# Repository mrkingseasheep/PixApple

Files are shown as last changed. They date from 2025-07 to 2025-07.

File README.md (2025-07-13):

# PixApple

PixApple is designed as a RP2040 breakout board. It features 8 general use GPIOs, 1 SPI interface, 1 I2C interface, 4 ADC channels, 4 PWM channels and a CAN bus.
I designed it because I wanted a board that I could use for general purpose robotics projects. Being from FRC, a CAN bus was a must so I added the CAN bus onto the RP2040 with split terminations.
The Roborio is like 2000CAD so it's so far out of reach its funny. Of course, I don't need the real time OS or the robust nature of the thing, I just want to drive a lil car or something. So I created this!
Building this project really gave me a greater understanding of what went on undernearth the Roborio (I never did open it) and everything actually kinda makes sense now.
I chose the RP2040 because it is cheap, decently powerful for the basic robotics I plan on doing with it and is also what I'm used to.
Additionally, I chose the 0603 SMT format because I wanted to be able to fix any problems I have later on with this board.
This being V1.0, many of the values are not tested and I wanted the ability to fix them if anything happened.
Finally, there are test points scattered around the board for easy debugging.

## What I've gained

Total time spent: 51 hours (I'm still so slow at KiCAD) (the redo didn't help)

This is my first semi-intermediate project and I wanted to learn more about ICs in general. I've incorporated: wide power traces, equal length wires and a ground pour on top and bottom in this project.

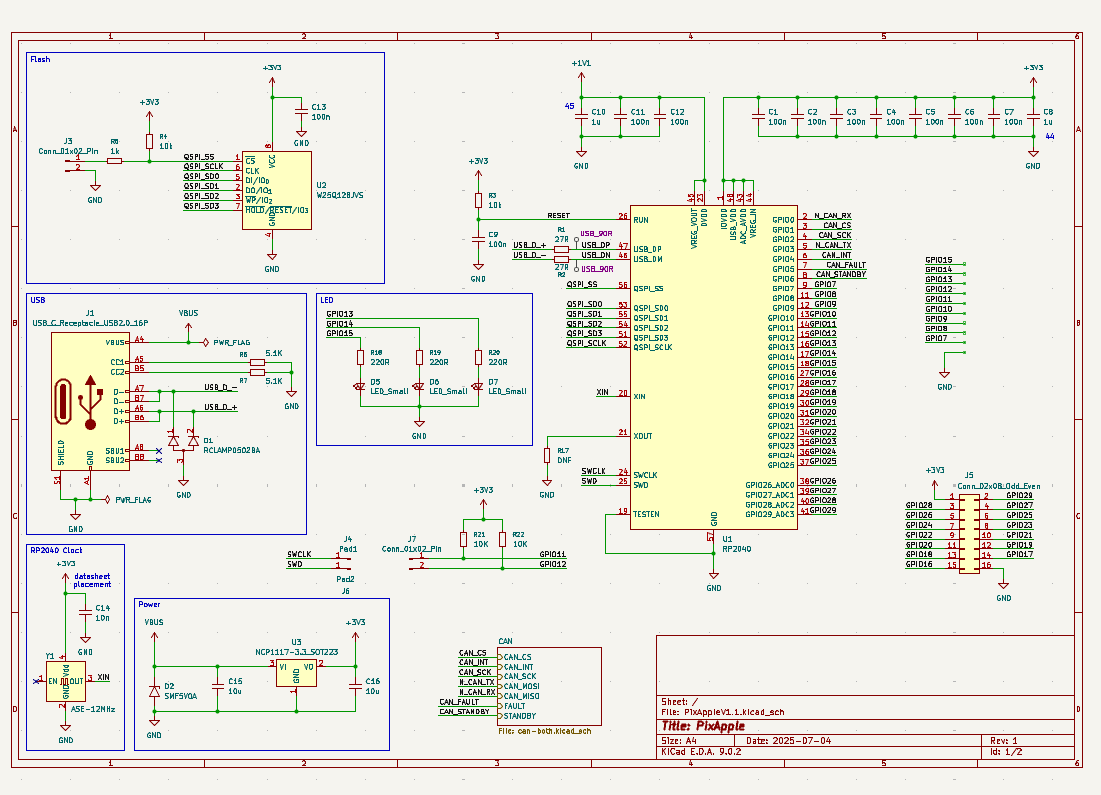
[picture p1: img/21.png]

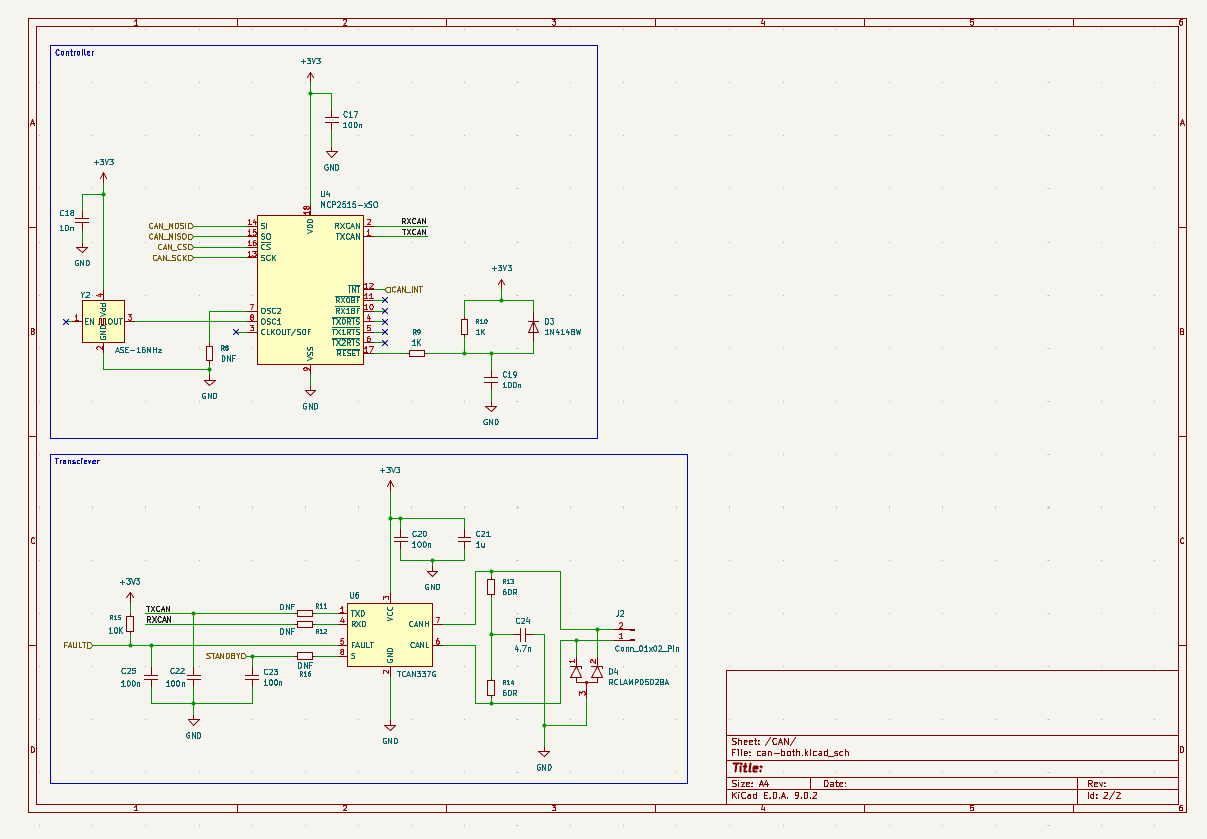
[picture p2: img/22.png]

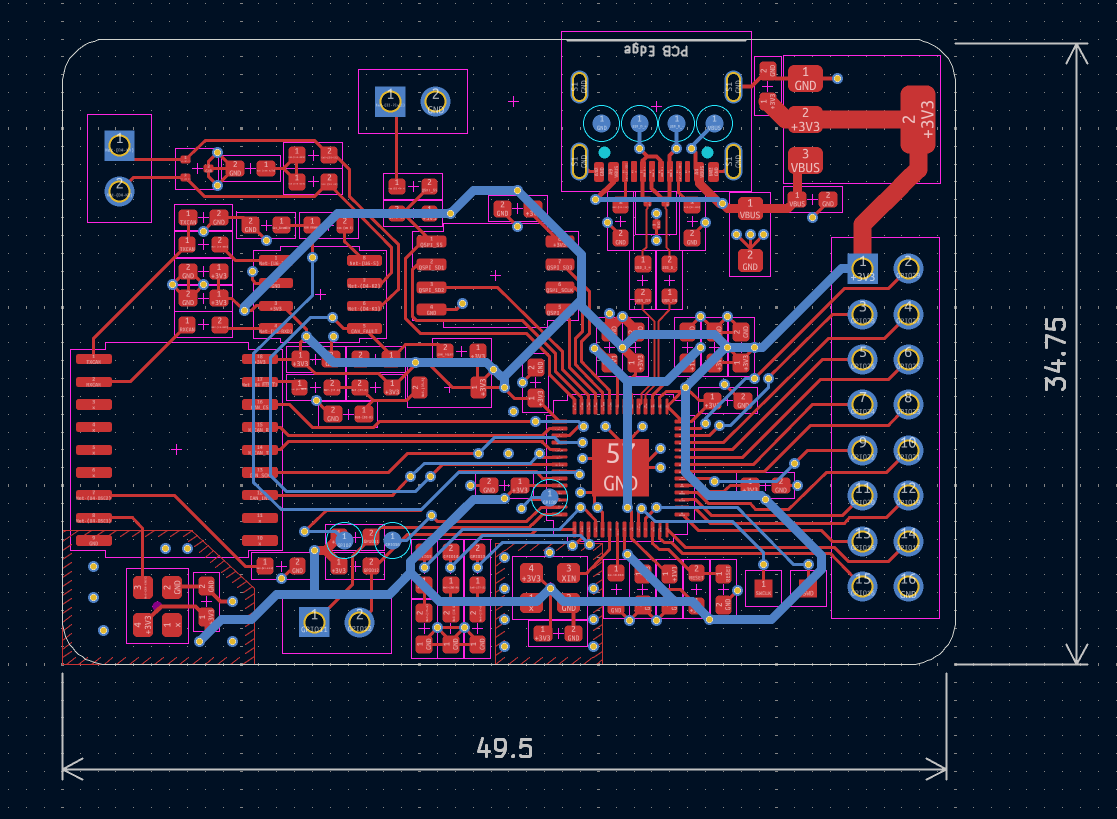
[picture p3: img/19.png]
PCB

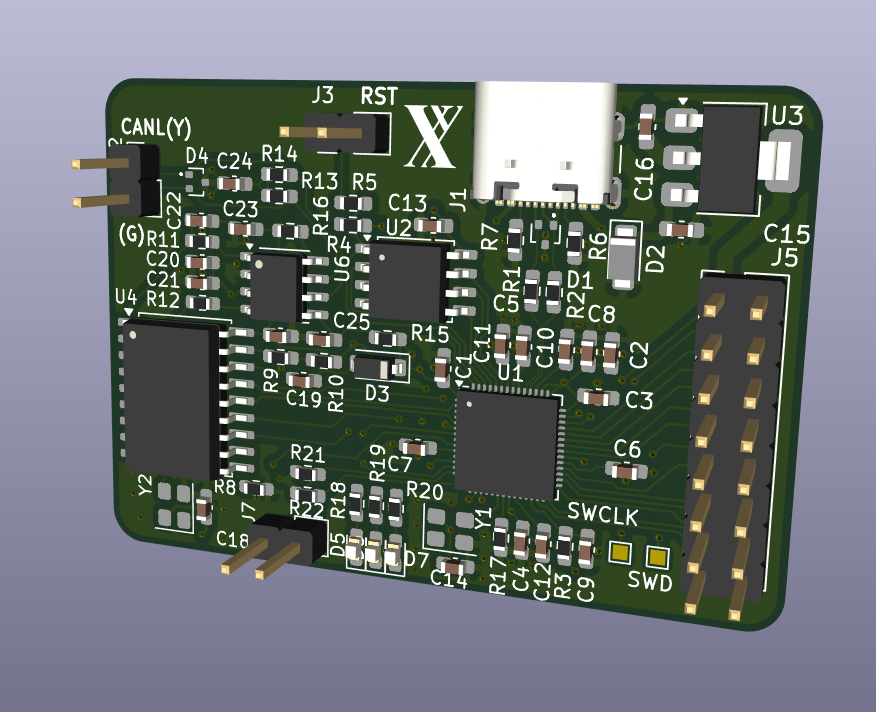
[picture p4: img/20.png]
3D

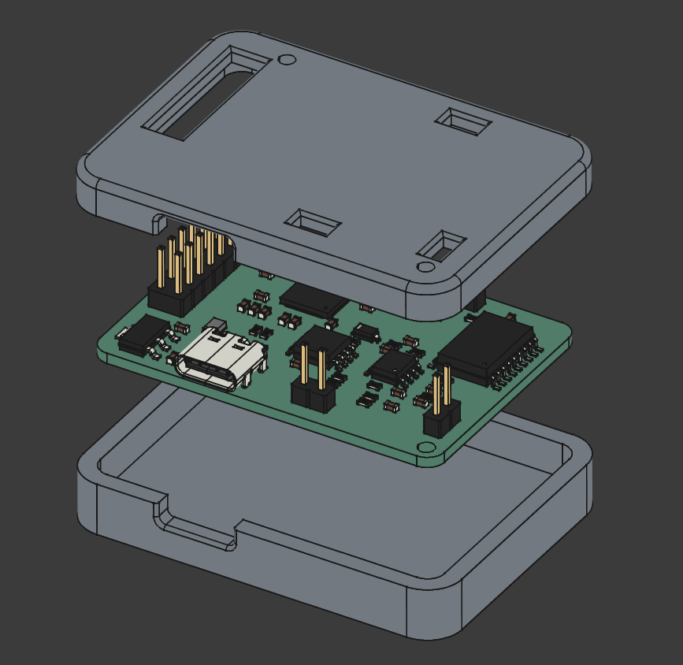
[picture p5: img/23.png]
Case

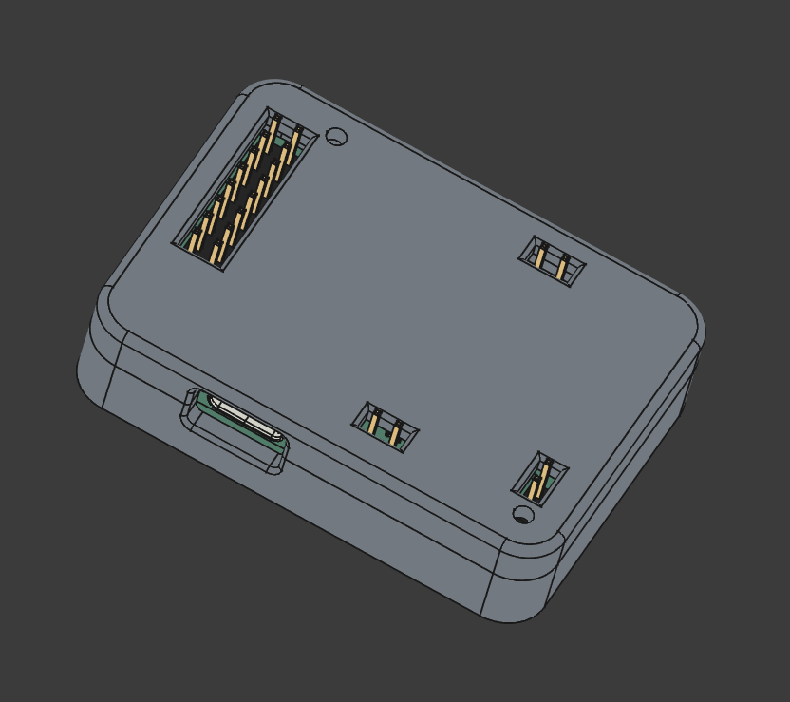
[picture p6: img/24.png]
Exploded


## BOM

| Quantity | Value | Cost | URL |
| --- | --- | --- | --- |
| 17 | Capacitor 100n | 0.068 | https://www.aliexpress.com/item/1005002782324319.html |
| 3 | Capacitor 1u | 0.012 | https://www.aliexpress.com/item/1005002782324319.html |
| 2 | Capacitor 10n | 0.008 | https://www.aliexpress.com/item/1005002782324319.html |
| 2 | Capacitor 10u | 0.008 | https://www.aliexpress.com/item/1005002782324319.html |
| 1 | Capacitor 4.7n | 0.004 | https://www.aliexpress.com/item/1005002782324319.html |
| 2 | TVS Diode RCLAMP0502BA | 2.50 | https://www.digikey.ca/en/products/detail/semtech-corporation/RCLAMP0502BATCT/2603604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 |
| 1 | SMF5V0A | 0.25 | https://www.digikey.ca/en/products/detail/vishay-general-semiconductor-diodes-division/SMF5V0A-E3-08/1680585 |
| 1 | 1N4148W | 0.014 | https://www.aliexpress.com/item/4000685043735.html |
| 3 | LED | 0.0525  | https://www.aliexpress.com/item/1005006211269173.html |
| 1 | USB_C_Receptacle_USB2.0_16P | 0.1875  | https://www.aliexpress.com/item/1005008515699009.html |
| 22 | 2.54mm Pins Male | 0.20295 | https://www.aliexpress.com/item/4001198421663.html |
| 2 | Resistor 27R | 0.01 | https://www.aliexpress.com/item/1005007902452631.html |
| 3 | Resistor 1K | 0.015 | https://www.aliexpress.com/item/1005007902452631.html |
| 5 | Resistor DNF | 0.025 | https://www.aliexpress.com/item/1005007902452631.html |
| 2 | Resistor 60R | 0.01 | https://www.aliexpress.com/item/1005007902452631.html |
| 5 | Resistor 10K | 0.025 | https://www.aliexpress.com/item/1005007902452631.html |
| 3 | Resistor 220R | 0.015 | https://www.aliexpress.com/item/1005007902452631.html |
| 2 | Resistor 5.1K | 0.01 | https://www.aliexpress.com/item/1005007902452631.html |
| 1 | RP2040 | 1.29 | https://www.canakit.com/raspberry-pi-rp2040.html?cid=cad&src=raspberrypi |
| 1 | W25Q128JVS | | JLCPCB Assembly |
| 1 | NCP1117-3.3_SOT223 | | JLCPCB Assembly |
| 1 | MCP2515-xSO | | JLCPCB Assembly |
| 1 | TCAN337G | | JLCPCB Assembly |
| 1 | ASE-12MHz | 1.56 | https://www.mouser.ca/ProductDetail/ABRACON/ASE-12.000MHZ-ET?qs=uDmhV2jwPRcj2BLg3gv24Q%3D%3D |
| 1 | ASE-16MHz | 1.53 | https://www.mouser.ca/ProductDetail/ABRACON/ASE-16.000MHZ-LC-T?qs=gt1LBUVyoHnfDWzQTg2whA%3D%3D |
| 1 | PCB | 75 | JLCPCB Assembly |
| 2 | Heat set insert | 0.10 | https://www.aliexpress.com/item/1005007653131713.html |
| 2 | M2 | 0.08 | https://www.aliexpress.com/item/32810872544.html |
| 1 | Case | 5 | Printing Legion |

Total: 80 CAD

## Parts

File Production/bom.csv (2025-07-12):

Designator | Footprint | Quantity | Value | LCSC Part #
C1, C11, C12, C13, C17, C19, C2, C20, C22, C23, C25, C3, C4, C5, C6, C7, C9 | 0603 | 17 | 100n
C10, C21, C8 | 0603 | 3 | 1u
C14, C18 | 0603 | 2 | 10n
C15, C16 | 0603 | 2 | 10u
C24 | 0603 | 1 | 4.7n
D1, D4 | SOT-416 | 2 | RCLAMP0502BA
D2 | D_SMF | 1 | SMF5V0A
D3 | D_SOD-123 | 1 | 1N4148W
D5, D6, D7 | 0603 | 3 | LED_Small
J1 | USB_C_Receptacle_GCT_USB4105-xx-A_16P_TopMnt_Horizontal | 1 | USB_C_Receptacle_USB2.0_16P
J2, J3, J7 | PinHeader_1x02_P2.54mm_Vertical | 3 | Conn_01x02_Pin
J5 | PinHeader_2x08_P2.54mm_Vertical | 1 | Conn_02x08_Odd_Even
R1, R2 | 0603 | 2 | 27R
R10, R5, R9 | 0603 | 3 | 1K
R11, R12, R16, R17, R8 | 0603 | 5 | DNF
R13, R14 | 0603 | 2 | 60R
R15, R21, R22, R3, R4 | 0603 | 5 | 10K
R18, R19, R20 | 0603 | 3 | 220R
R6, R7 | 0603 | 2 | 5.1K
SWCLK | TestPoint_Pad_1.0x1.0mm | 1 | Pad1
SWD | TestPoint_Pad_1.0x1.0mm | 1 | Pad2
U1 | QFN-56-1EP_7x7mm_P0.4mm_EP3.2x3.2mm | 1 | RP2040
U2 | SOIC-8_5.3x5.3mm_P1.27mm | 1 | W25Q128JVS
U3 | SOT-223-3_TabPin2 | 1 | NCP1117-3.3_SOT223
U4 | SOIC-18W_7.5x11.6mm_P1.27mm | 1 | MCP2515-xSO
U6 | SOIC-8_3.9x4.9mm_P1.27mm | 1 | TCAN337G
Y1 | Oscillator_SMD_Abracon_ASE-4Pin_3.2x2.5mm | 1 | ASE-12MHz
Y2 | Oscillator_SMD_Abracon_ASE-4Pin_3.2x2.5mm | 1 | ASE-16MHz

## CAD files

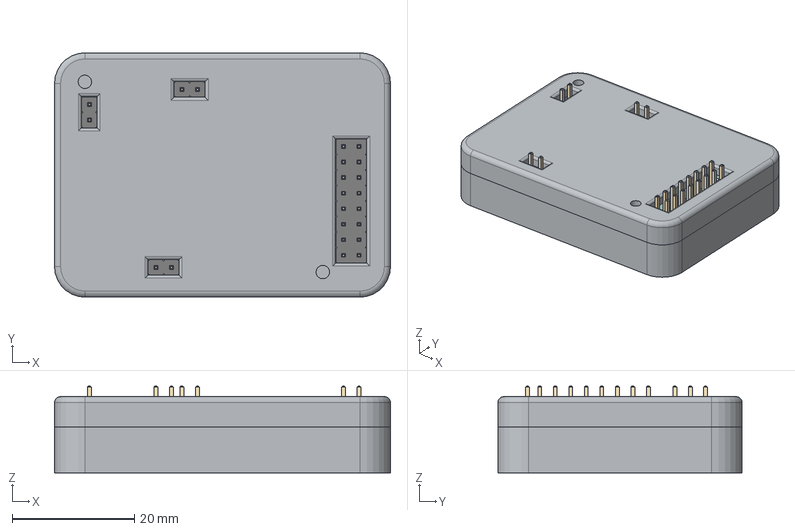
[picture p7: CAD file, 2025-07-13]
Case/case.step
55.0 x 40.0 x 14.2 mm
R_0603_1608Metric x 22
PinHeader_2x08_P2.54mm_Vertical
LED_0603_1608Metric x 3
C_0603_1608Metric x 25
SOIC-8_3.9x4.9mm_P1.27mm
SOIC-8_5.3x5.3mm_P1.27mm
D_SMF
SOT-223
D_SOD-123
QFN-56-1EP_7x7mm_P0.4mm_EP3.2x3.2mm
USB_C_Receptacle_GCT_USB4105-xx-A_16P_TopMnt_Horizontal
USB_C_Receptacle_GCT_USB4105-xx-A_16P_TopMnt_Horizontal001
USB_C_Receptacle_GCT_USB4105-xx-A_16P_TopMnt_Horizontal002
USB_C_Receptacle_GCT_USB4105-xx-A_16P_TopMnt_Horizontal003
USB_C_Receptacle_GCT_USB4105-xx-A_16P_TopMnt_Horizontal004
USB_C_Receptacle_GCT_USB4105-xx-A_16P_TopMnt_Horizontal005
USB_C_Receptacle_GCT_USB4105-xx-A_16P_TopMnt_Horizontal006
USB_C_Receptacle_GCT_USB4105-xx-A_16P_TopMnt_Horizontal007
USB_C_Receptacle_GCT_USB4105-xx-A_16P_TopMnt_Horizontal008
USB_C_Receptacle_GCT_USB4105-xx-A_16P_TopMnt_Horizontal009
USB_C_Receptacle_GCT_USB4105-xx-A_16P_TopMnt_Horizontal010
USB_C_Receptacle_GCT_USB4105-xx-A_16P_TopMnt_Horizontal011
USB_C_Receptacle_GCT_USB4105-xx-A_16P_TopMnt_Horizontal012
USB_C_Receptacle_GCT_USB4105-xx-A_16P_TopMnt_Horizontal013
USB_C_Receptacle_GCT_USB4105-xx-A_16P_TopMnt_Horizontal014
USB_C_Receptacle_GCT_USB4105-xx-A_16P_TopMnt_Horizontal015
USB_C_Receptacle_GCT_USB4105-xx-A_16P_TopMnt_Horizontal016
USB_C_Receptacle_GCT_USB4105-xx-A_16P_TopMnt_Horizontal017
USB_C_Receptacle_GCT_USB4105-xx-A_16P_TopMnt_Horizontal018
USB_C_Receptacle_GCT_USB4105-xx-A_16P_TopMnt_Horizontal019
USB_C_Receptacle_GCT_USB4105-xx-A_16P_TopMnt_Horizontal020
USB_C_Receptacle_GCT_USB4105-xx-A_16P_TopMnt_Horizontal021
USB_C_Receptacle_GCT_USB4105-xx-A_16P_TopMnt_Horizontal022
USB_C_Receptacle_GCT_USB4105-xx-A_16P_TopMnt_Horizontal023
USB_C_Receptacle_GCT_USB4105-xx-A_16P_TopMnt_Horizontal024
USB_C_Receptacle_GCT_USB4105-xx-A_16P_TopMnt_Horizontal025
USB_C_Receptacle_GCT_USB4105-xx-A_16P_TopMnt_Horizontal026
USB_C_Receptacle_GCT_USB4105-xx-A_16P_TopMnt_Horizontal027
USB_C_Receptacle_GCT_USB4105-xx-A_16P_TopMnt_Horizontal028
USB_C_Receptacle_GCT_USB4105-xx-A_16P_TopMnt_Horizontal029
USB_C_Receptacle_GCT_USB4105-xx-A_16P_TopMnt_Horizontal030
USB_C_Receptacle_GCT_USB4105-xx-A_16P_TopMnt_Horizontal031
USB_C_Receptacle_GCT_USB4105-xx-A_16P_TopMnt_Horizontal032
USB_C_Receptacle_GCT_USB4105-xx-A_16P_TopMnt_Horizontal033
USB_C_Receptacle_GCT_USB4105-xx-A_16P_TopMnt_Horizontal034
USB_C_Receptacle_GCT_USB4105-xx-A_16P_TopMnt_Horizontal035
PinHeader_1x02_P2.54mm_Vertical x 3
SOIC-18W_7.5x11.6mm_P1.27mm
PixAppleV1.1_PCB

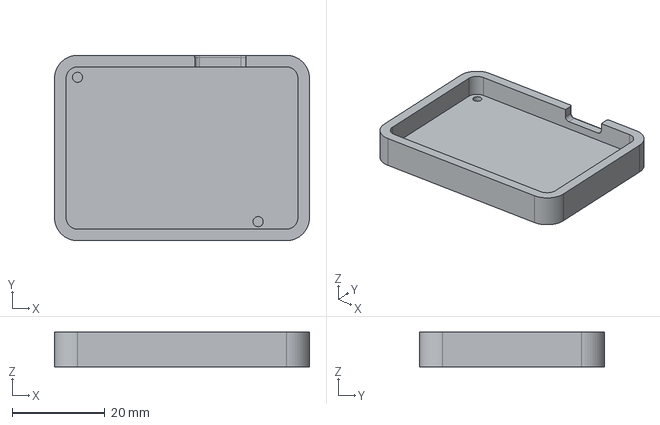
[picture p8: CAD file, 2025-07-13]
Production/case-bottom.step
55.0 x 40.0 x 7.50 mm

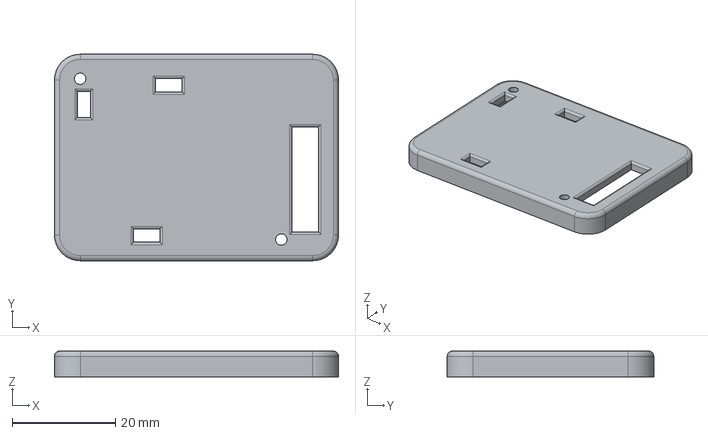
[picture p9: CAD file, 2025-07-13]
Production/case-top.step
55.0 x 40.0 x 5.00 mm

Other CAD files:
Case/case.FCStd

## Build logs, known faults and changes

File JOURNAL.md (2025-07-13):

---
title: "PixApple"
author: "Xinyang Wang"
description: "RP2040 Development Board"
created_at: "2025-07-04"
---

Total time spent: 38 hours (yes I'm slow)

# 2025-07-04 - Where to begin (5 hours)

This is a starter project so I can learn how to actually design a keyborad with the RP2040.
So far I've decided on Bluetooth support + battery charging.
I'm tempted to make it waterproof, whatever that means for a development board, so I can stick it in a submarine sometime in the future. Who knows. Maybe.
So far I've done the relatively basic task of setting it up with the power capacitors, pull up resistors and the likes. Only gripe I have right now is reading documentation is a chore.

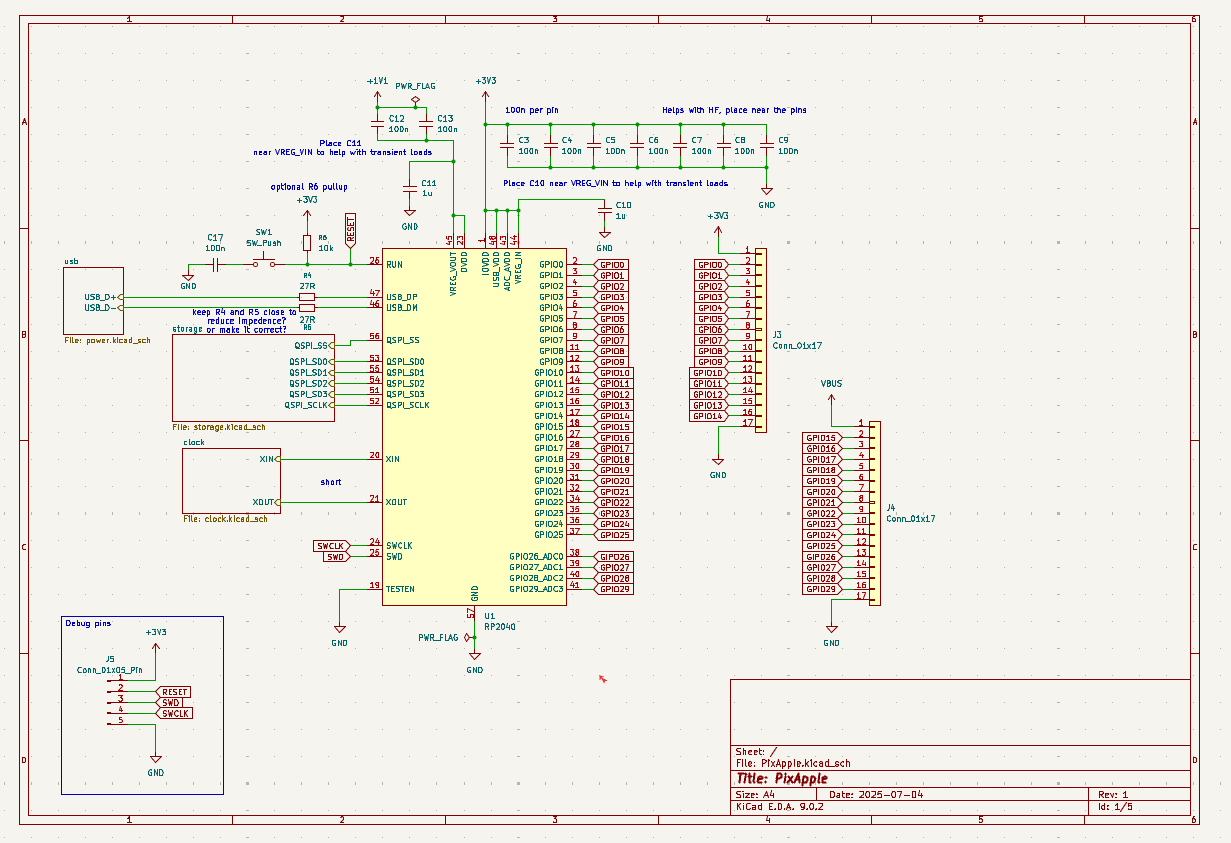
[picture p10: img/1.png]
Schematic start


# 2025-07-05 - CAN we do it? no (3 hours)

I want CAN. It'll make routing logic/commands/data to and from various parts a lot easier. Only problem is I have no idea what controllers to use. A preliminary search shows that the MCP2515 the CAN controller is a good fit but the transmitter the MCP2551 isn't. MCP2515 can handle +3V3 while MCP2551 needs +5V. So we're ditching MCP2551 for SN65HVD230. Whoever named these needs to be uhhh.... questioned.

Work is slow. So many pages of documentation on documentation. Mainly getting the crystal oscillator and reset pin of all things working. And guess what! My hirearchical sheet was drawn in the wrong grid size because I somehow clicked N by accident. That screws up all the tags and you can't connect to them. Now I have to redraw the sheet. I hate KiCAD sometimes. Why on earth would it let you change grid size if it'll break everything in the schematic??? I'm sleeping now.

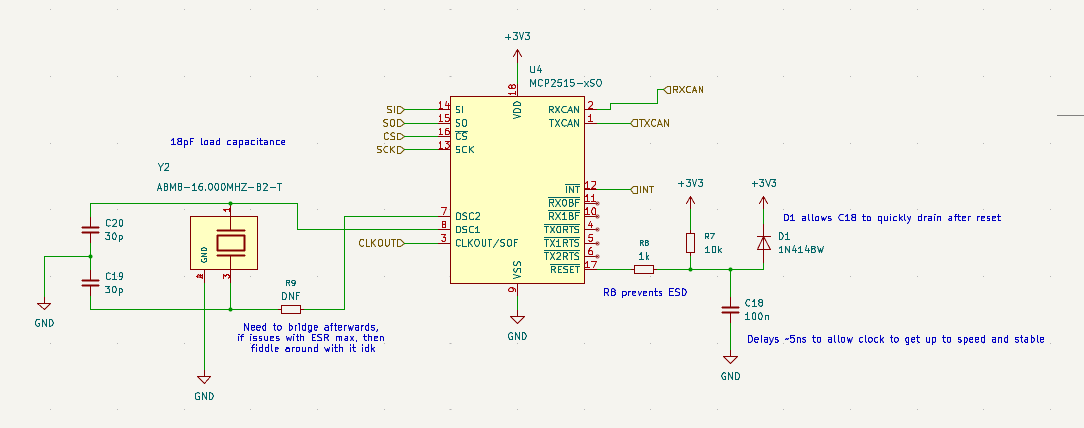
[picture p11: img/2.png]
MCP2515 design

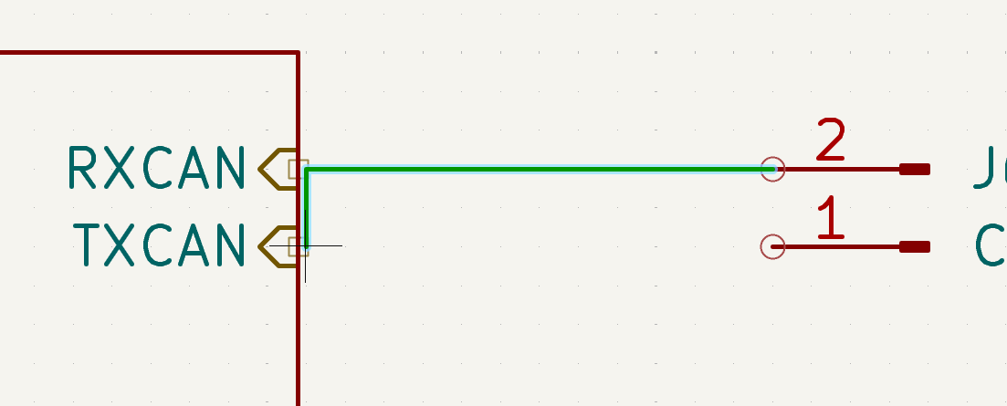
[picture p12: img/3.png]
GRRRRR


# 2025-07-06 - CAN re-schematic (5 hours)

Redo following (https://ww1.microchip.com/downloads/en/DeviceDoc/MCP2515-Stand-Alone-CAN-Controller-with-SPI-20001801J.pdf). Hopefully it went fine. The only thing that I'm slightly sketched out by is the series resistor R9 in the CAN clock. I'm not really sure how to calculate it and the ABM8-16MHz datasheet says nothing about it (https://abracon.com/Resonators/abm8.pdf). For now I'll just use the same resistor the RP2040 docs said to use with the ABM8-272 but hey at least I can desolder it if needed.

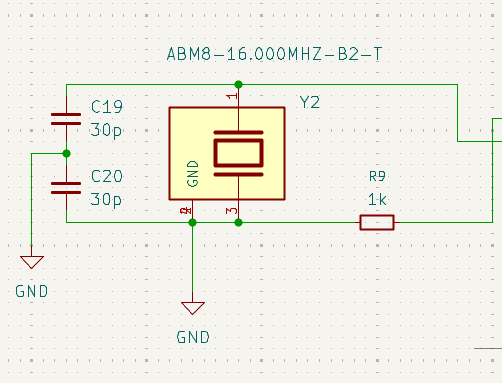
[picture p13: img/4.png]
Sketchyyy


Use this to figure out what pins the IC can actually connect to (https://datasheets.raspberrypi.com/rp2040/rp2040-datasheet.pdf).

DRC finally has no complaints! I hate rewiring though. Time to add the CAN transmitter (https://www.ti.com/lit/ds/symlink/sn65hvd230.pdf?ts=1751731839553). Yippee JLCPCB has it as a part (how much does assembly cost... I'm scared this'll be super super expensive). We're doing split termination on the CAN bus because we can. Also because I dunno if my signal will be clear at all so I'd much rather have a working CAN bus than a dysfunctional one. I finished schematic-ing up the CAN controller, the MCP2515 and the transmitter, the SN65HVD230DR.

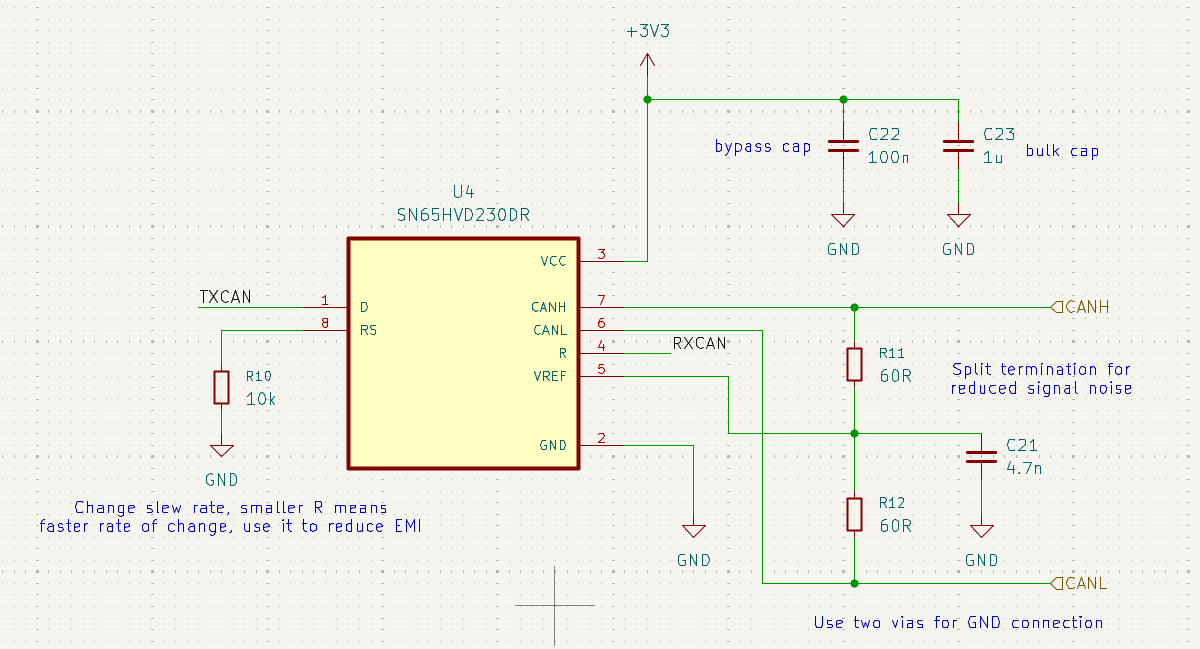
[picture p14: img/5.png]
CAN Done


# 2025-07-07 - Breakout (8 hours)

https://youtu.be/ySuUZEjARPY
Goated video.

Finished the schematic. Hopefully.

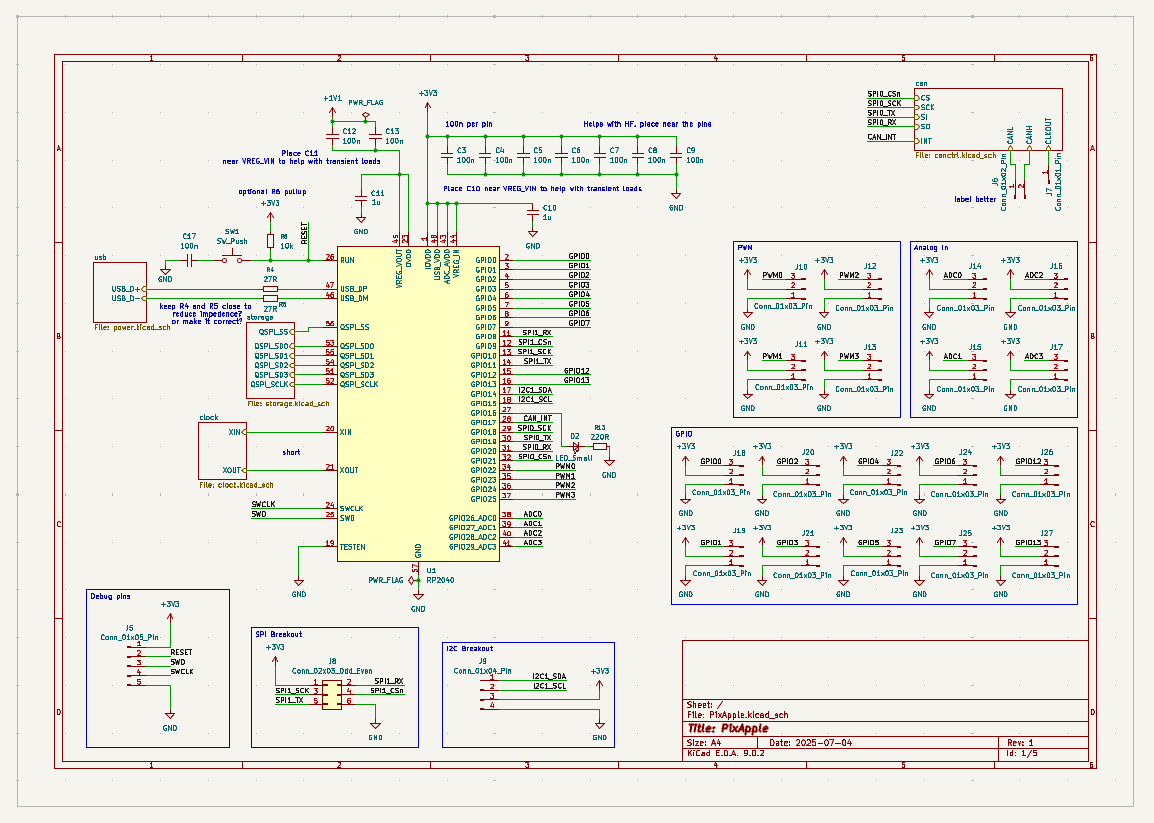
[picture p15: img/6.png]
Headers done


Added all footprints.

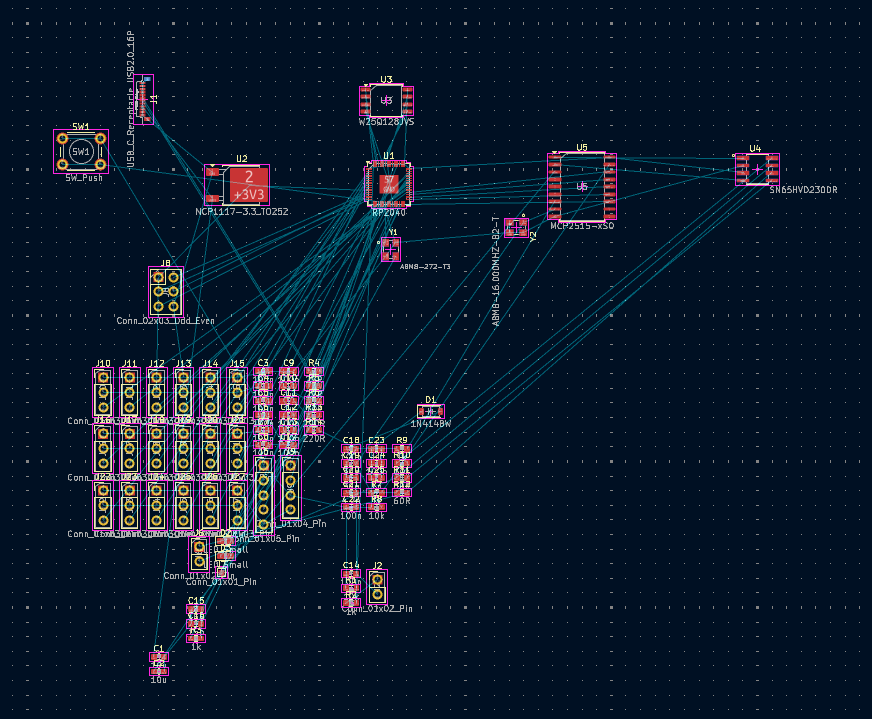
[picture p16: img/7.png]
One big rat


That was a total mess. I'll finish the rest of it tomorrow. Routing the CAN chip looks fun. The lines are all crossed and I'm scared that the vias will mess up the ground plane somehow.

# 2025-07-08 - Redo (6 hours)

Ok so uh I might be stupid and I might have placed all my components too close together. And uhhh... Well whoops they intersect physically so it's time for a complete redo. Yay. I'm having fun! (it is kinda fun though)

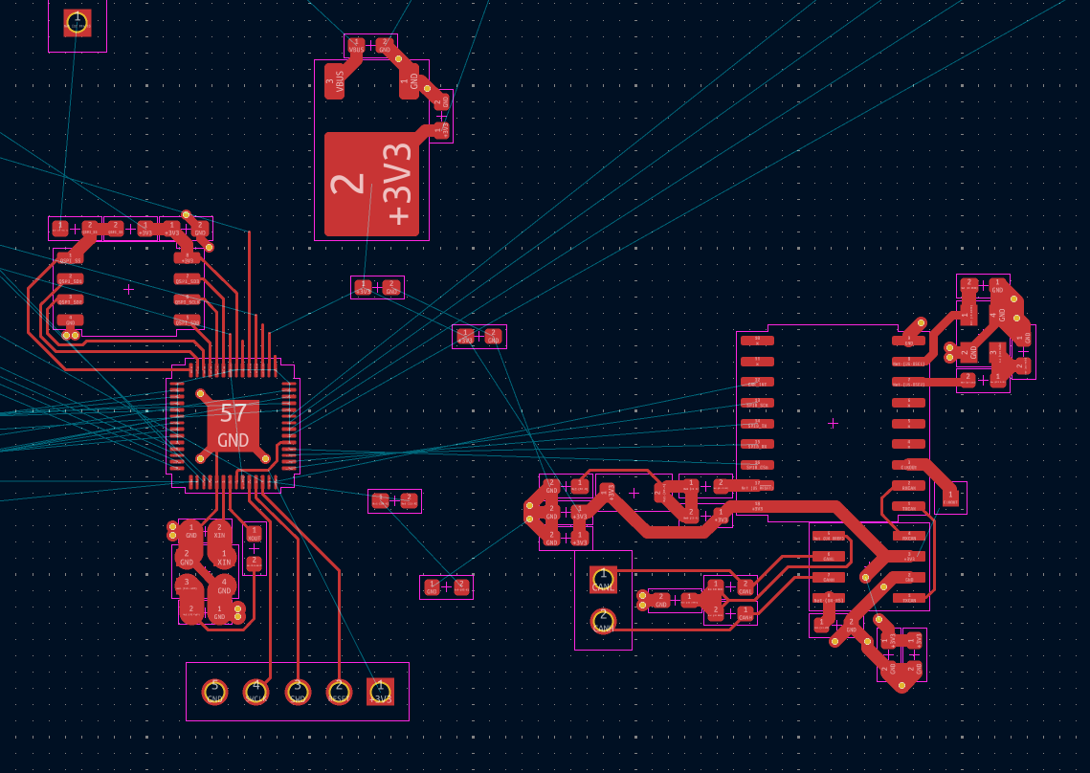
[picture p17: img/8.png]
Yet Another Redo

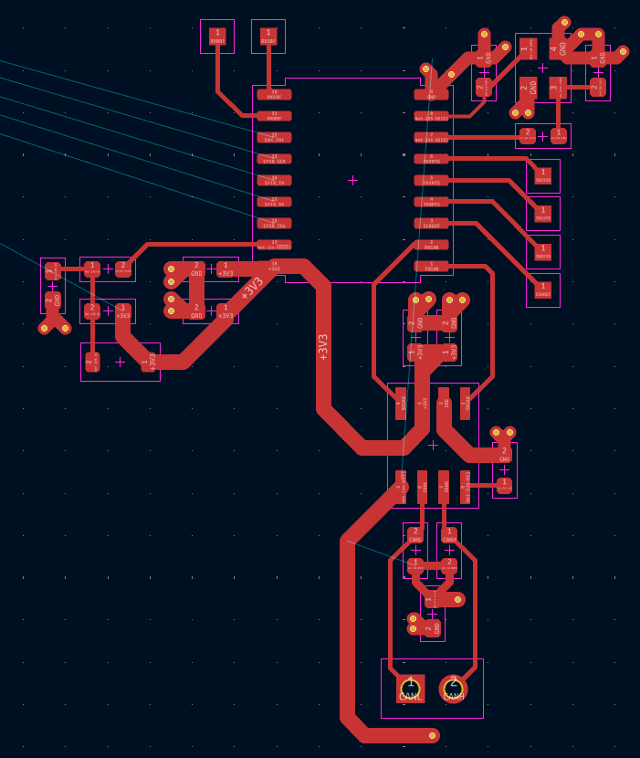
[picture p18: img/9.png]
Going well so far


Routing this is a pain. I'm using 0603 SMT parts because I want to practice soldering SMTs however that means that I can't fit my desired number of capacitors on the board. There's simply too many of them at the top of the RP2040 there. Alas.

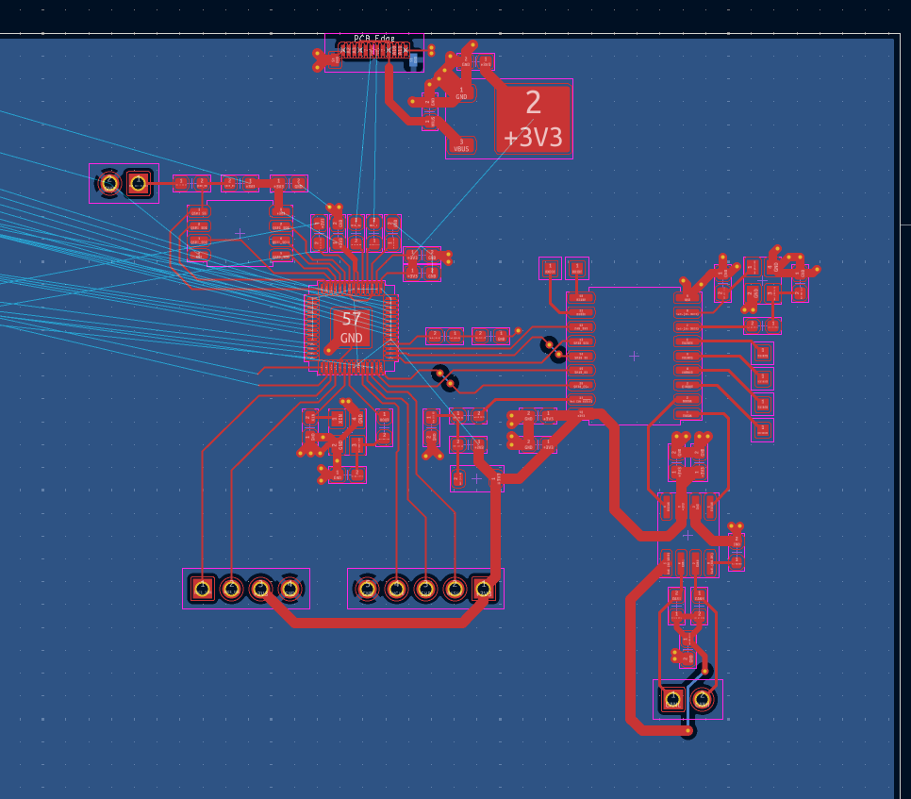
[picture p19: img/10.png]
PCB Design 101


# 2025-07-09 - FINALLY (8 hours)

It's done! Holy... It's been a journey. Routing the end was a pain and I'm 99% sure that the 0.9mm wide power traces will be fine. I didn't quite manage to use all the capacitors for the +3V3 but it should be fine. I think I might just finish by adding a connector for a battery or external +5V input. But then I'm done! Also the beveled edges are quite nice.

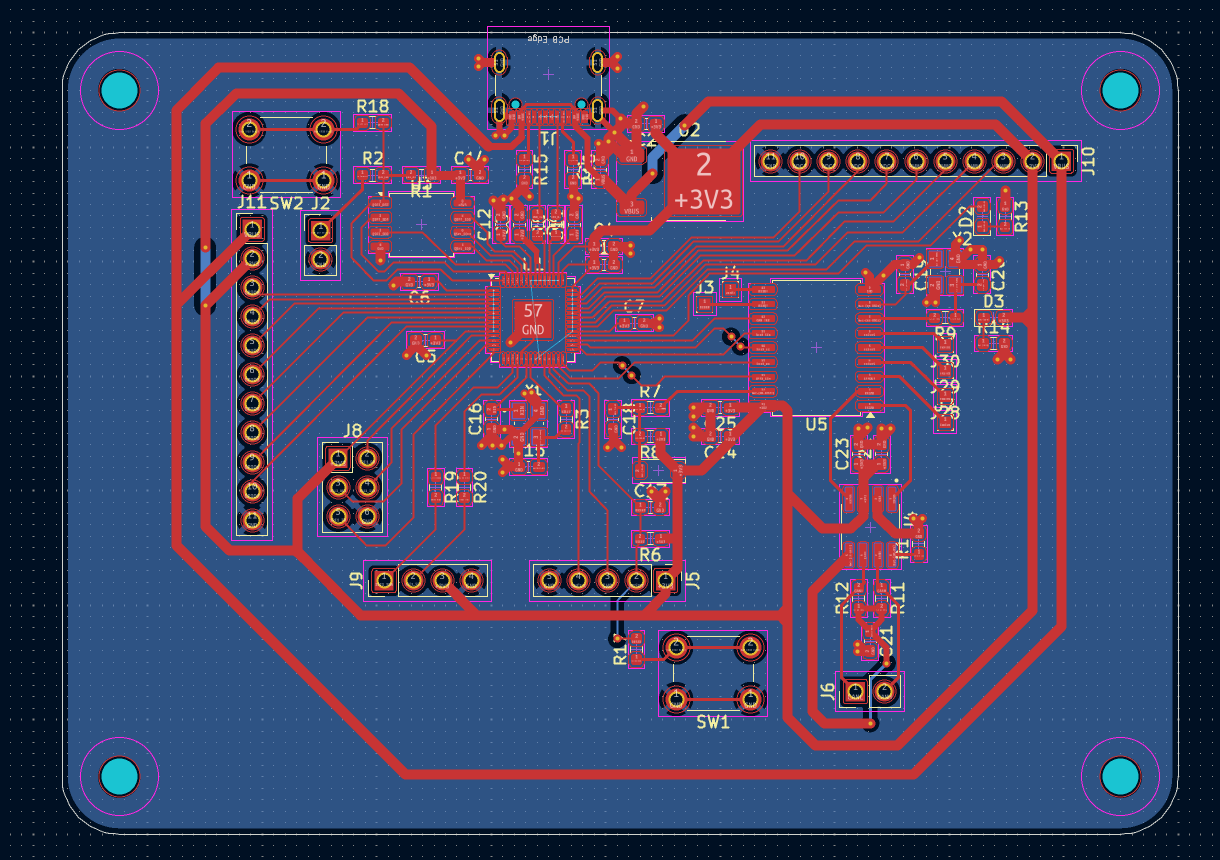
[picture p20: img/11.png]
99% Completion


Wait I just realized I need to fix the soldermask now oh dear. This'll be painful.
Update: It's done. I've added a power pin for battery power, diodes to prevent overflow, and a ground pour on the top layer.
All that's left is to add some decorative silkscreen and it'll be ready to ship.

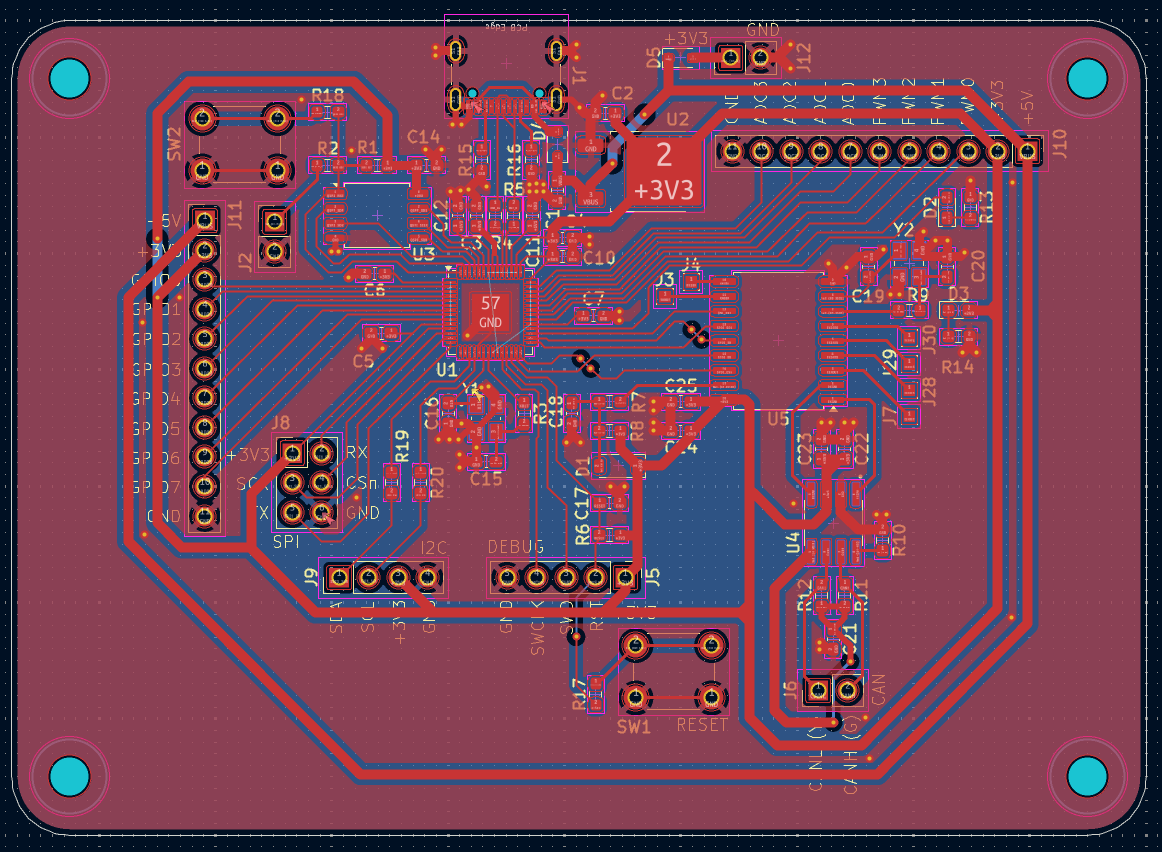
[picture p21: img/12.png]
We done

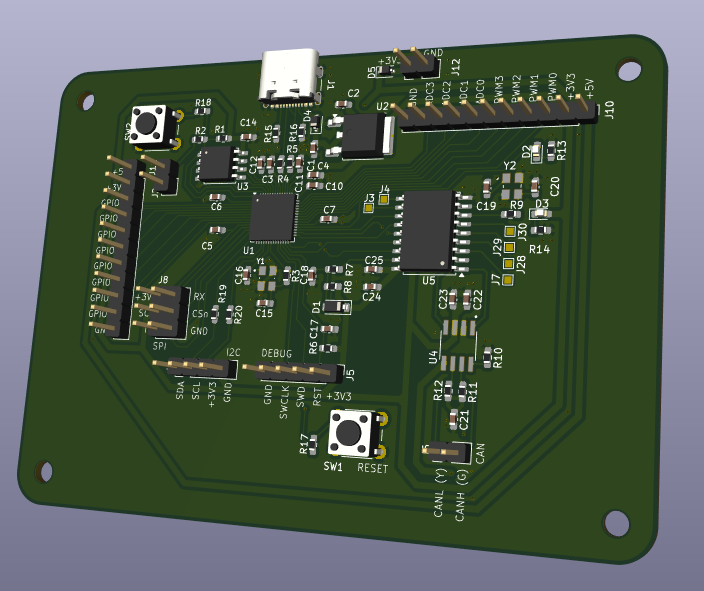
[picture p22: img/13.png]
Front


# 2025-07-10 - Final notes (3 hours)

Fixed the +3V3 and +1V1 rails, added ESD protection, better edge.cuts

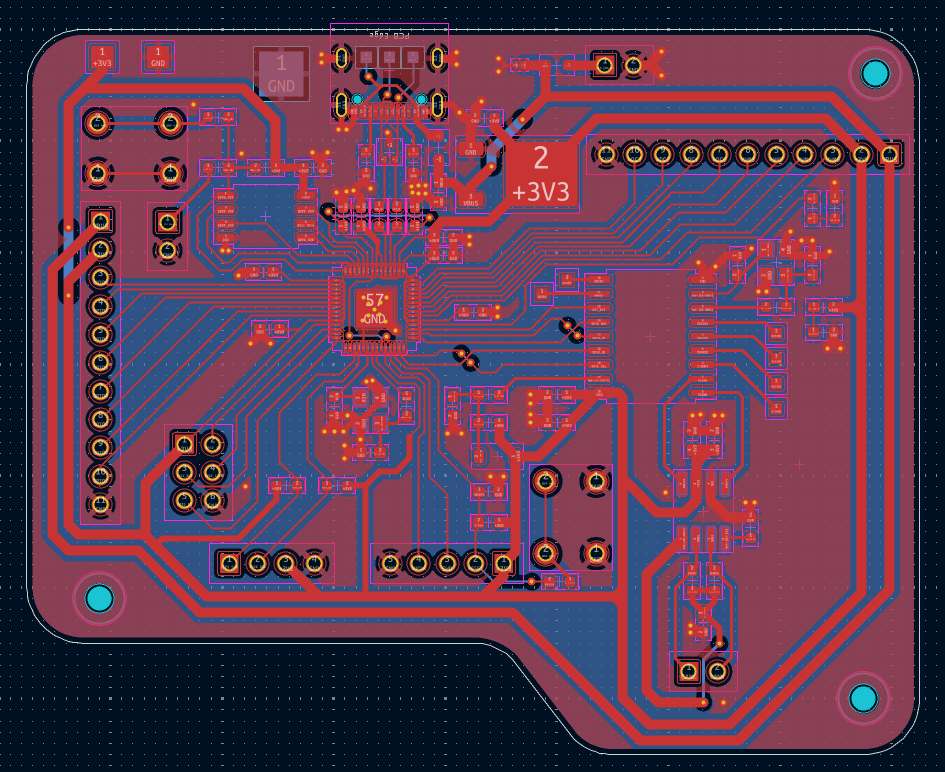
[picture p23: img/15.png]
New and improved


# 2025-07-11 - Restarting (3 hours)

Oh dear it's all bad gonna restart. Redo the differential pairs (CAN and USB), better routing.

# 2025-07-12 - Routing gone good (13 hours)

New schematic. New pcb grouping. I'm pooped. I'm putting the SMT components closer together now to hopefully make things more efficient??

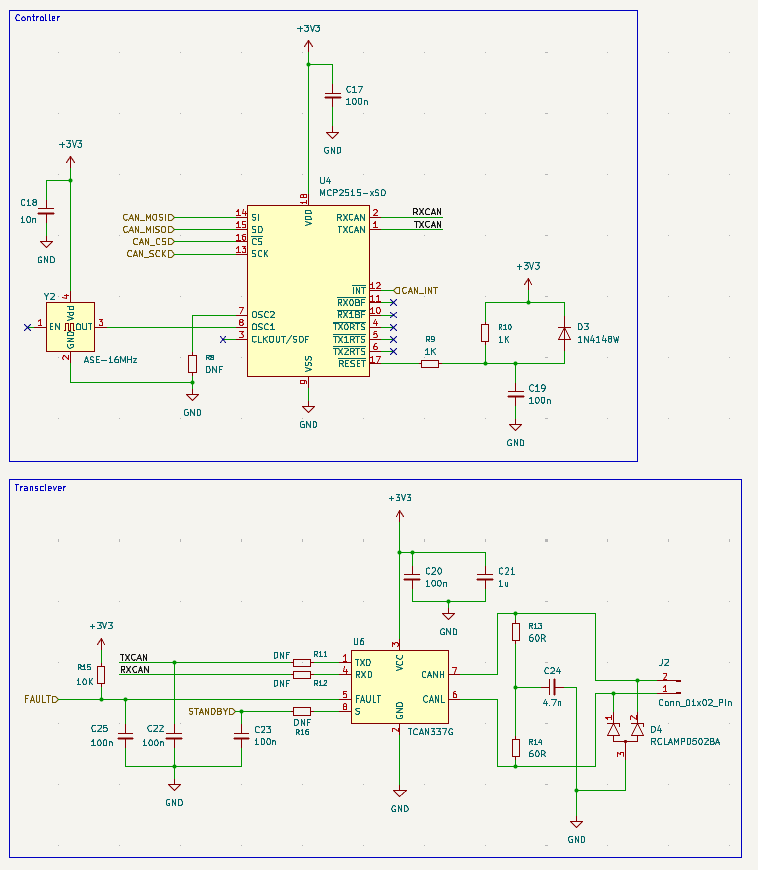
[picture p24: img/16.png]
CAN New

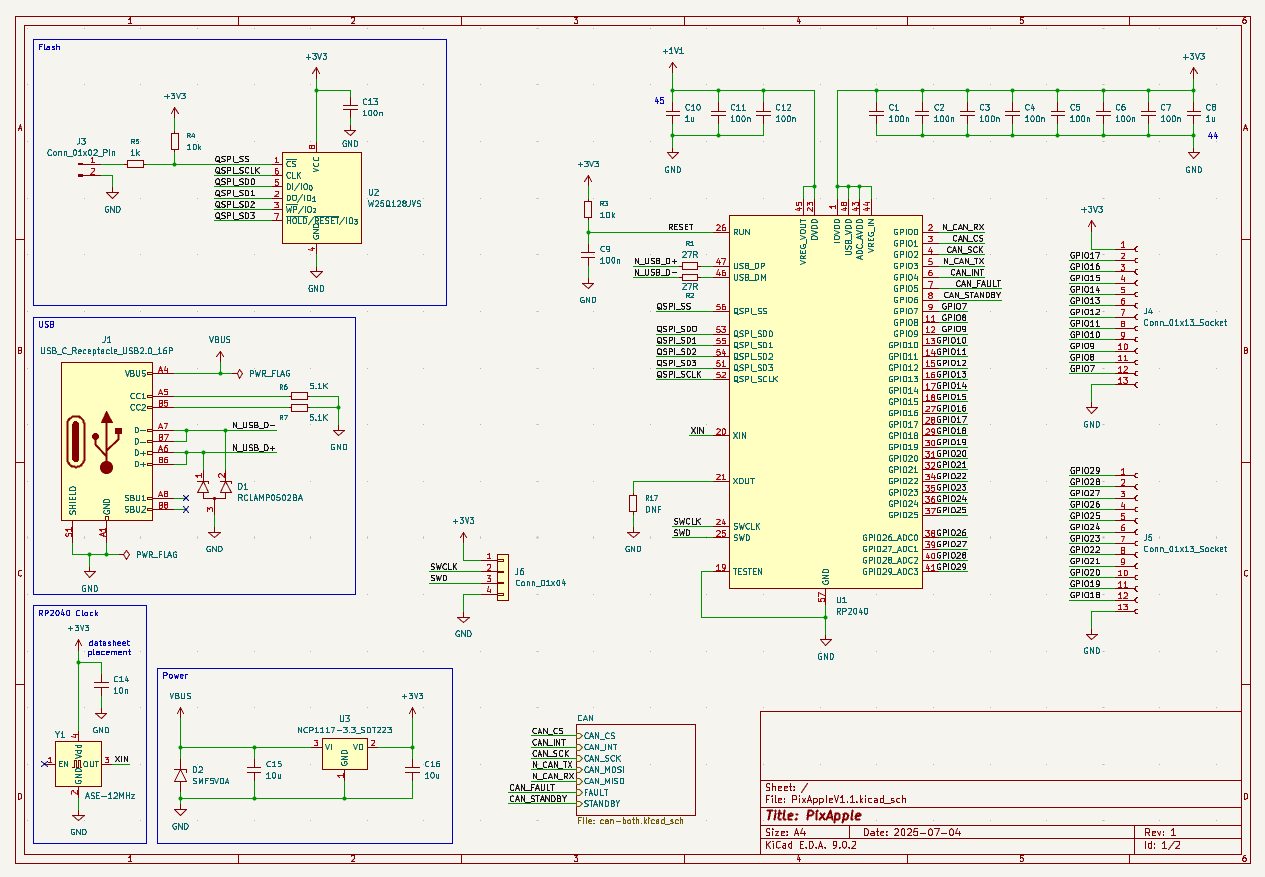
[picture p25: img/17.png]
RP2040 Schematic


The grind never stops. Complete overhaul, new modules (using an oscillator), 4 layer board WITHIN the 50mmx50mm limits (I'm so proud of this). Inner two ground planes. Using TCAN337 instead of old CAN transciever. ESD protection on USB datalines, VBUS and CAN headers. I'm so tired.

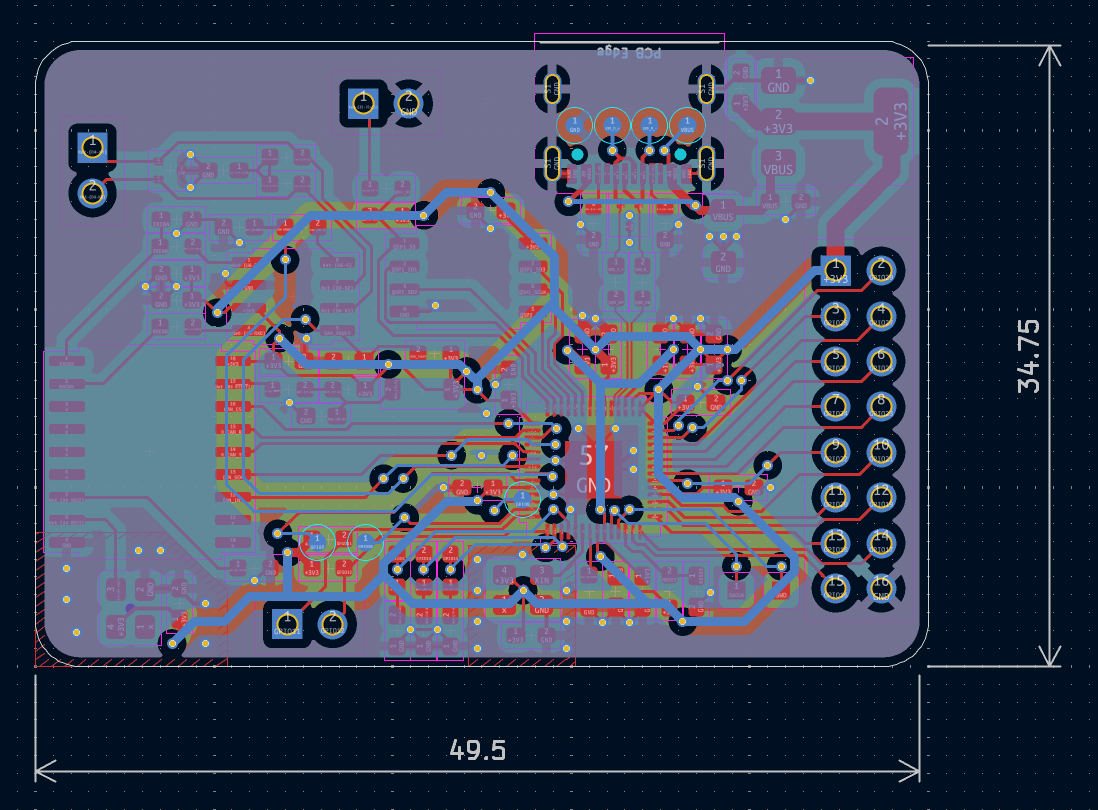
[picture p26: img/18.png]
Rainbow PCB

Just the lines
ITS BEAUTIFUL

# 2025-07-13 - Case (2 hours)

Added a case

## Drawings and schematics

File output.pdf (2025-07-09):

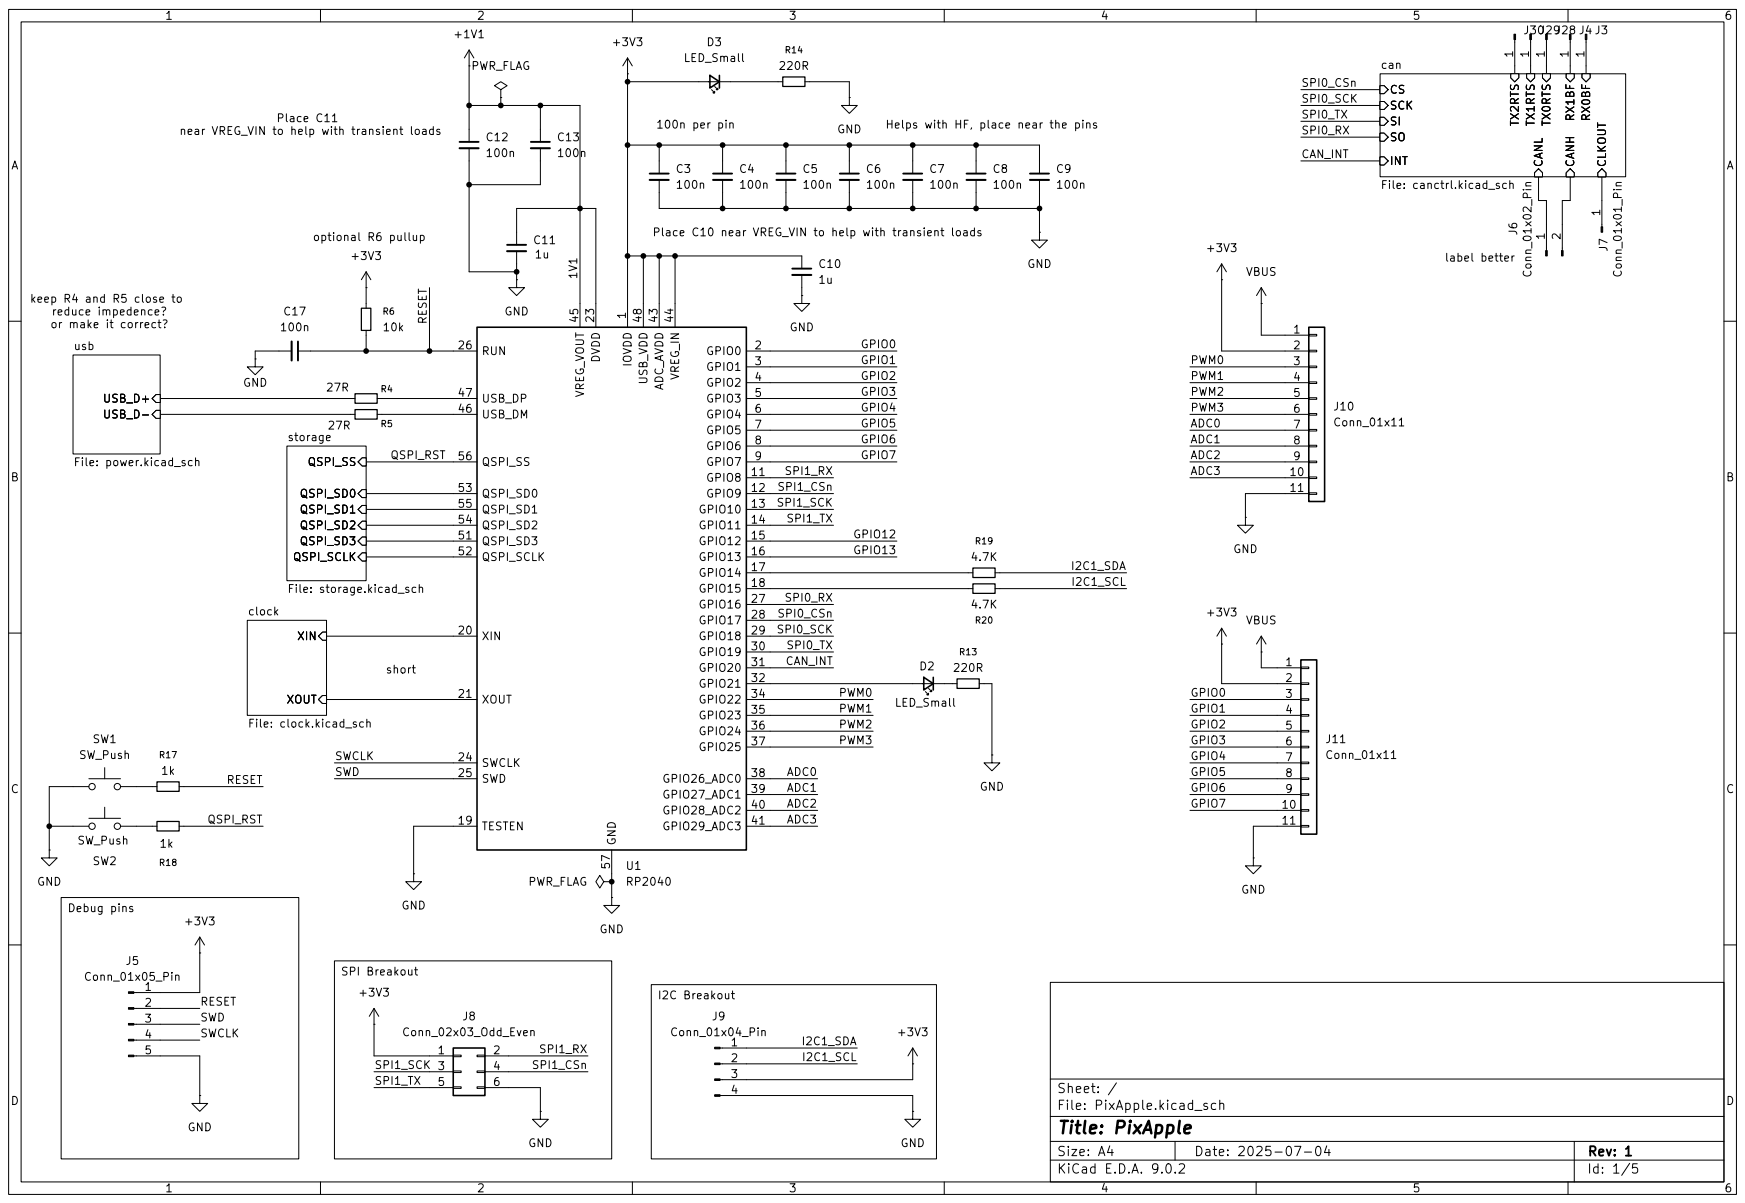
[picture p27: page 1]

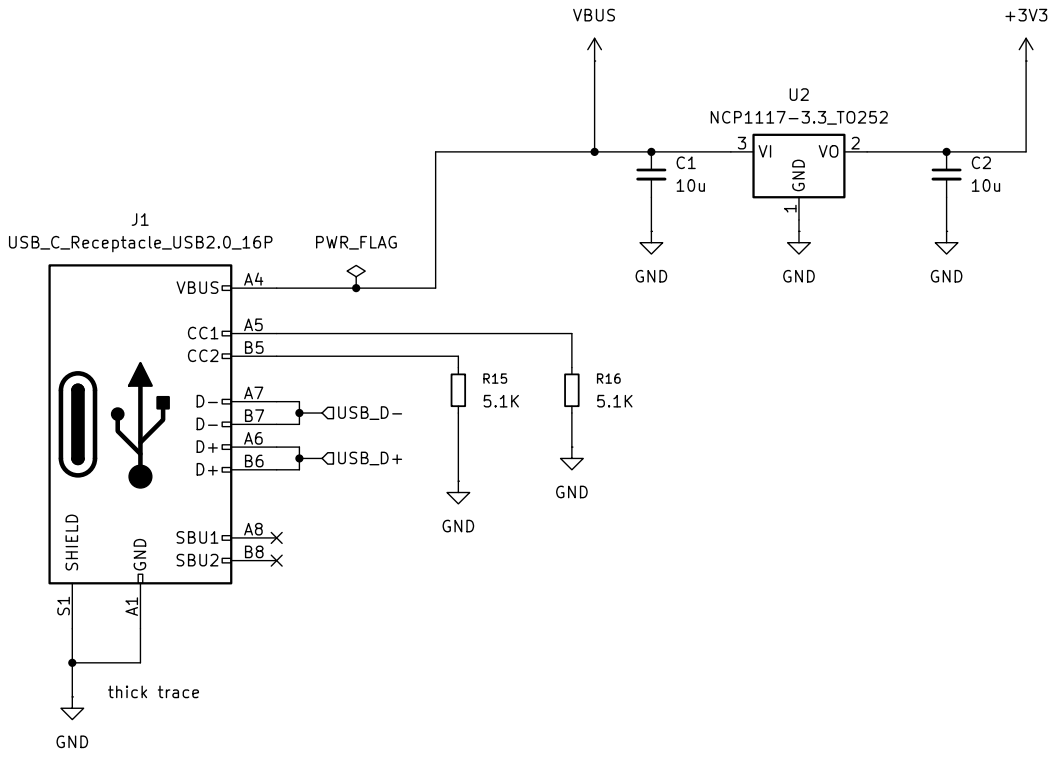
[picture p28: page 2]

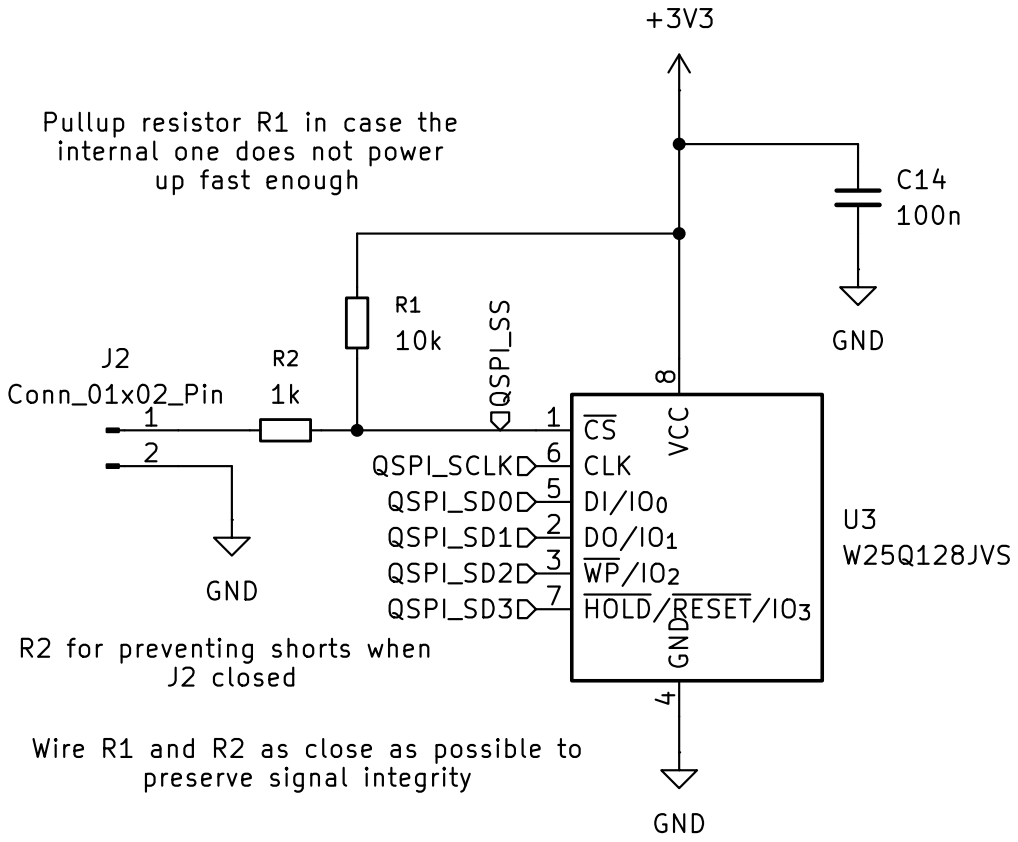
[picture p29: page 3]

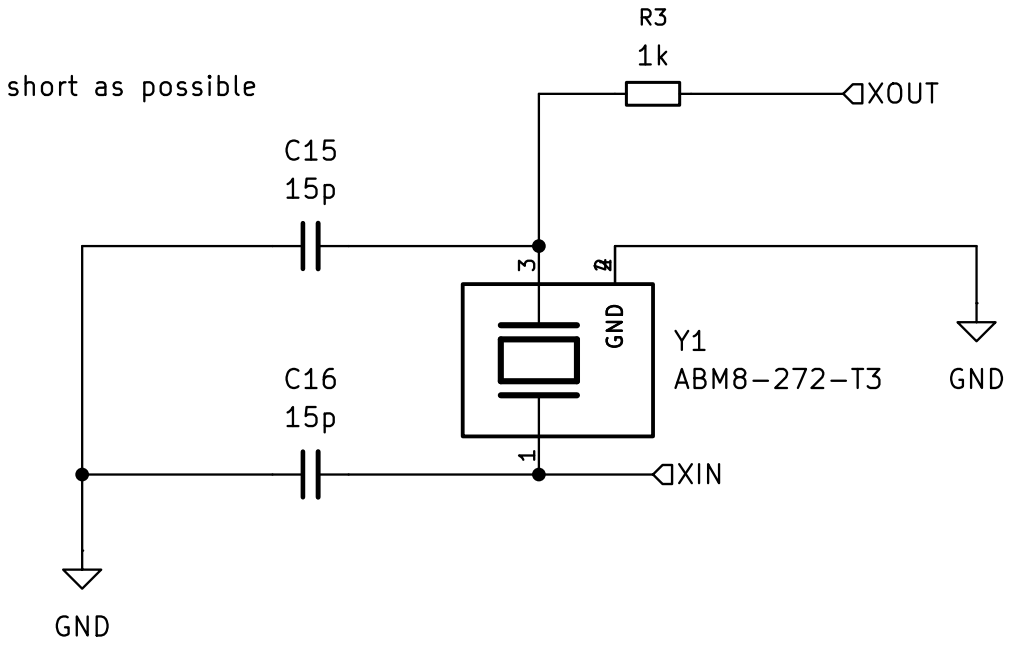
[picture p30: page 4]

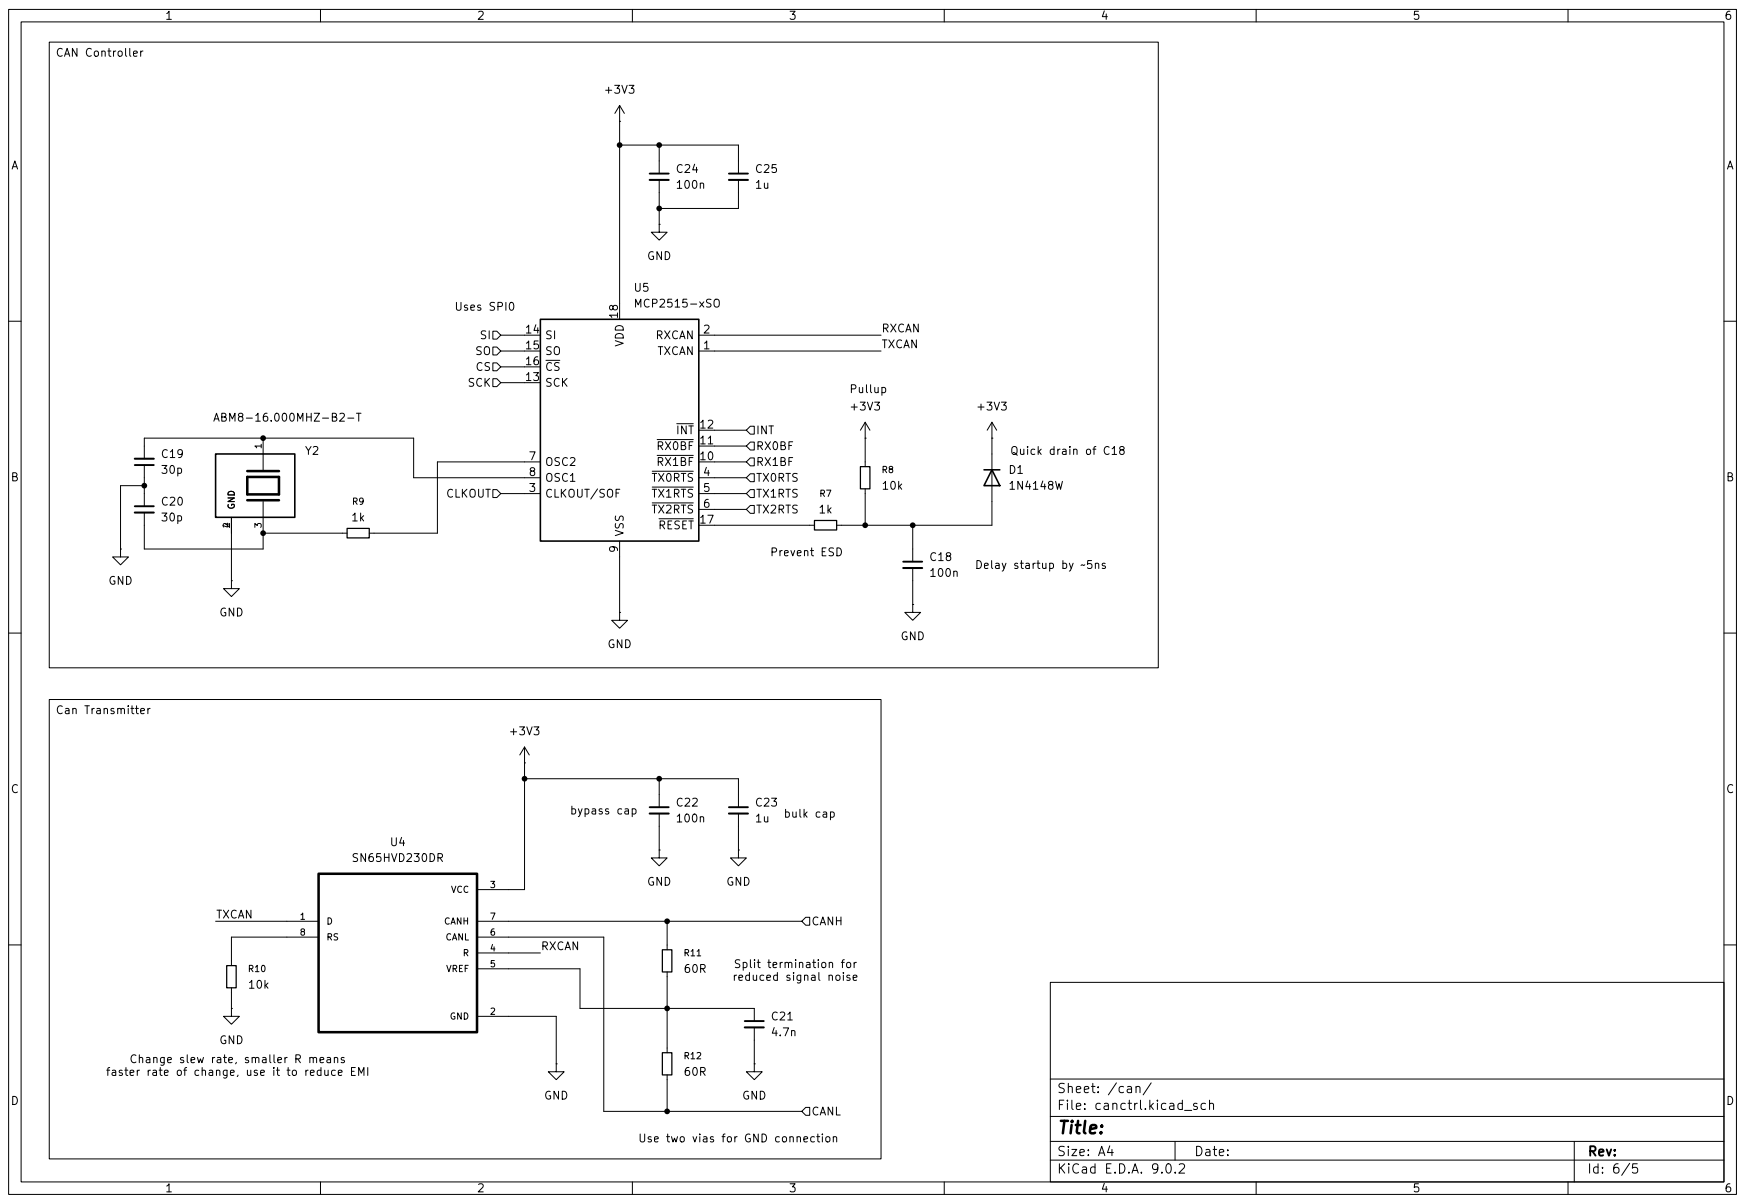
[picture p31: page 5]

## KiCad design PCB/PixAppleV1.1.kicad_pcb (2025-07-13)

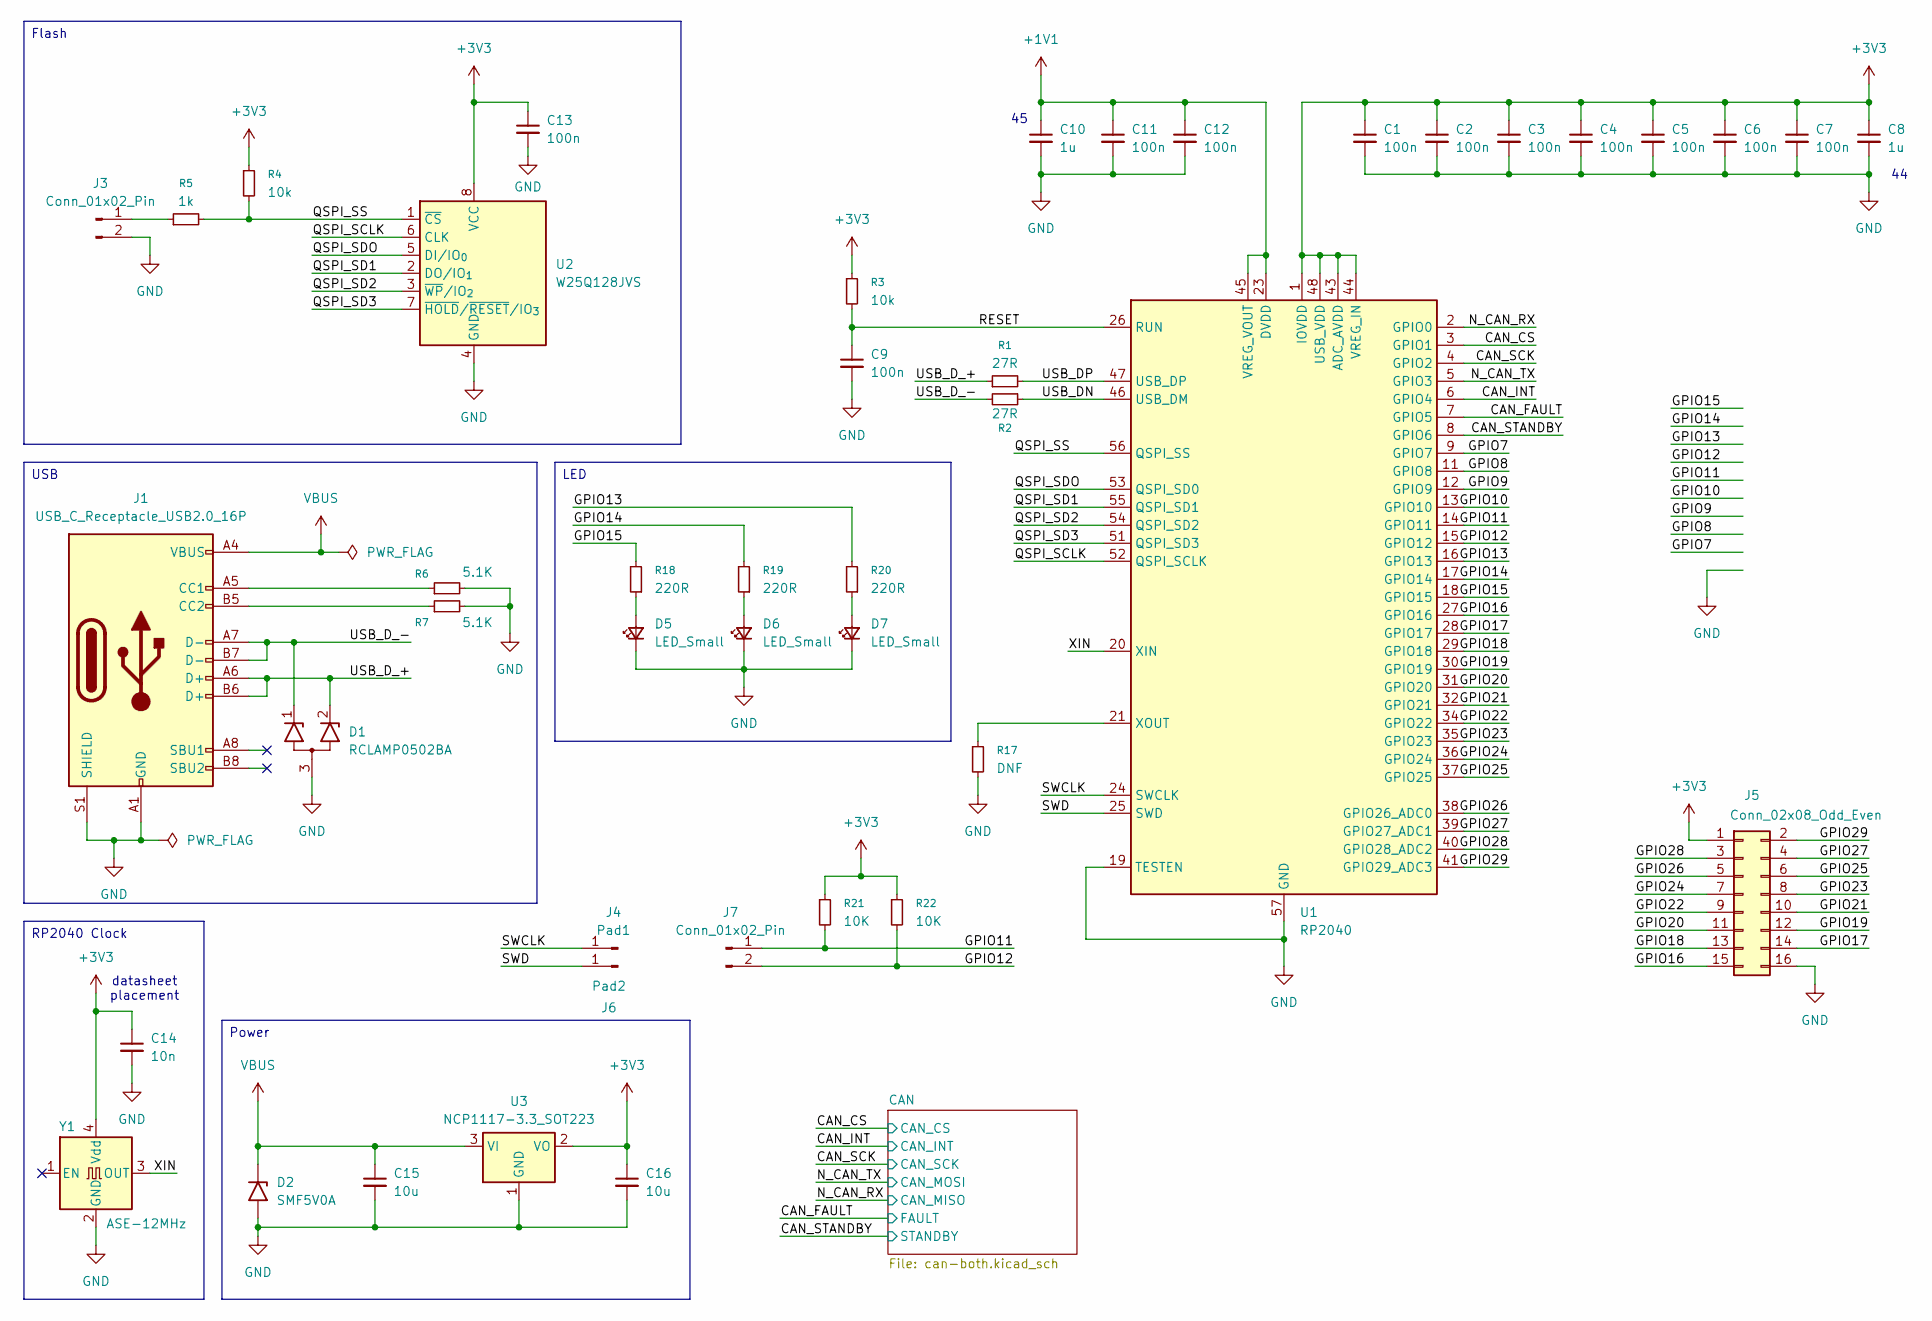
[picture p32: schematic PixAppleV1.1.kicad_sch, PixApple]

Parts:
C1, C2, C3, C4, C5, C6, C7, C9, C11, C12, C13: 100n; C_0603_1608Metric_Pad1.08x0.95mm_HandSolder
C8, C10: 1u; C_0603_1608Metric_Pad1.08x0.95mm_HandSolder
C14: 10n; C_0603_1608Metric_Pad1.08x0.95mm_HandSolder
C15, C16: 10u; C_0603_1608Metric_Pad1.08x0.95mm_HandSolder
D1: RCLAMP0502BA; SOT-416
D2: SMF5V0A; D_SMF
D5, D6, D7: LED_Small; LED_0603_1608Metric_Pad1.05x0.95mm_HandSolder
J1: USB_C_Receptacle_USB2.0_16P; USB_C_Receptacle_GCT_USB4105-xx-A_16P_TopMnt_Horizontal
J3, J7: Conn_01x02_Pin; PinHeader_1x02_P2.54mm_Vertical
J4: Pad1; TestPoint_Pad_1.0x1.0mm
J5: Conn_02x08_Odd_Even; PinHeader_2x08_P2.54mm_Vertical
J6: Pad2; TestPoint_Pad_1.0x1.0mm
R1, R2: 27R; R_0603_1608Metric_Pad0.98x0.95mm_HandSolder
R3, R4: 10k; R_0603_1608Metric_Pad0.98x0.95mm_HandSolder
R5: 1k; R_0603_1608Metric_Pad0.98x0.95mm_HandSolder
R6, R7: 5.1K; R_0603_1608Metric_Pad0.98x0.95mm_HandSolder
R17: DNF; R_0603_1608Metric_Pad0.98x0.95mm_HandSolder
R18, R19, R20: 220R; R_0603_1608Metric_Pad0.98x0.95mm_HandSolder
R21, R22: 10K; R_0603_1608Metric_Pad0.98x0.95mm_HandSolder
U1: RP2040; QFN-56-1EP_7x7mm_P0.4mm_EP3.2x3.2mm
U2: W25Q128JVS; SOIC-8_5.3x5.3mm_P1.27mm
U3: NCP1117-3.3_SOT223; SOT-223-3_TabPin2
Y1: ASE-12MHz; Oscillator_SMD_Abracon_ASE-4Pin_3.2x2.5mm

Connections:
+1V1: C10.1, C11.1, C12.1, U1.23 (DVDD), U1.45 (VREG_VOUT), U1.50 (DVDD)
+3V3: C1.1, C2.1, C3.1, C4.1, C5.1, C6.1, C7.1, C8.1, C13.1, C14.1, C16.1, J5.1, R3.1, R4.1, R21.1, R22.1, U1.1 (IOVDD), U1.10 (IOVDD), U1.22 (IOVDD), U1.33 (IOVDD), U1.42 (IOVDD), U1.43 (ADC_AVDD), U1.44 (VREG_IN), U1.48 (USB_VDD), U1.49 (IOVDD), U2.8 (VCC), U3.2 (VO), Y1.4 (Vdd); also elsewhere on the board
/CAN_CS: U1.3 (GPIO1); also elsewhere on the board
/CAN_FAULT: U1.7 (GPIO5); also elsewhere on the board
/CAN_INT: U1.6 (GPIO4); also elsewhere on the board
/CAN_SCK: U1.4 (GPIO2); also elsewhere on the board
/CAN_STANDBY: U1.8 (GPIO6); also elsewhere on the board
/GPIO7: U1.9 (GPIO7); also elsewhere on the board
/GPIO8: U1.11 (GPIO8)
/GPIO9: U1.12 (GPIO9); also elsewhere on the board
/GPIO10: U1.13 (GPIO10); also elsewhere on the board
/GPIO11: J7.1, R21.2, U1.14 (GPIO11)
/GPIO12: J7.2, R22.2, U1.15 (GPIO12)
/GPIO13: R20.2, U1.16 (GPIO13)
/GPIO14: R19.2, U1.17 (GPIO14)
/GPIO15: R18.2, U1.18 (GPIO15)
/GPIO16: J5.15, U1.27 (GPIO16)
/GPIO17: J5.14, U1.28 (GPIO17)
/GPIO18: J5.13, U1.29 (GPIO18)
/GPIO19: J5.12, U1.30 (GPIO19)
/GPIO20: J5.11, U1.31 (GPIO20)
/GPIO21: J5.10, U1.32 (GPIO21)
/GPIO22: J5.9, U1.34 (GPIO22)
/GPIO23: J5.8, U1.35 (GPIO23)
/GPIO24: J5.7, U1.36 (GPIO24)
/GPIO25: J5.6, U1.37 (GPIO25)
/GPIO26: J5.5, U1.38 (GPIO26_ADC0)
/GPIO27: J5.4, U1.39 (GPIO27_ADC1)
/GPIO28: J5.3, U1.40 (GPIO28_ADC2)
/GPIO29: J5.2, U1.41 (GPIO29_ADC3)
/N_CAN_RX: U1.2 (GPIO0); also elsewhere on the board
/N_CAN_TX: U1.5 (GPIO3); also elsewhere on the board
/QSPI_SCLK: U1.52 (QSPI_SCLK), U2.6 (CLK)
/QSPI_SD1: U1.55 (QSPI_SD1), U2.2 (DO/IO_{1})
/QSPI_SD2: U1.54 (QSPI_SD2), U2.3 (~WP/IO_{2})
/QSPI_SD3: U1.51 (QSPI_SD3), U2.7 (~HOLD/~RESET/IO_{3})
/QSPI_SDO: U1.53 (QSPI_SD0), U2.5 (DI/IO_{0})
/QSPI_SS: R4.2, R5.2, U1.56 (QSPI_SS), U2.1 (~CS)
/RESET: C9.1, R3.2, U1.26 (RUN)
/SWCLK: J4.1, U1.24 (SWCLK); also elsewhere on the board
/SWD: J6.1, U1.25 (SWD); also elsewhere on the board
/USB_DN: R2.1, U1.46 (USB_DM)
/USB_DP: R1.2, U1.47 (USB_DP)
/USB_D_+: D1.2 (K2), J1.A6 (D+), J1.B6 (D+), R1.1; also elsewhere on the board
/USB_D_-: D1.1 (K1), J1.A7 (D-), J1.B7 (D-), R2.2; also elsewhere on the board
/XIN: U1.20 (XIN), Y1.3 (OUT)
GND: C1.2, C2.2, C3.2, C4.2, C5.2, C6.2, C7.2, C8.2, C9.2, C10.2, C11.2, C12.2, C13.2, C14.2, C15.2, C16.2, D1.3 (A), D2.2 (A2), D5.1 (K), D6.1 (K), D7.1 (K), J1.A1 (GND), J1.A12 (GND), J1.B1 (GND), J1.B12 (GND), J1.S1 (SHIELD), J3.2, J5.16, R6.2, R7.2, R17.2, U1.19 (TESTEN), U1.57 (GND), U2.4 (GND), U3.1 (GND), Y1.2 (GND); also elsewhere on the board
unnamed: D5.2 (A), R18.1
unnamed: D6.2 (A), R19.1
unnamed: D7.2 (A), R20.1
unnamed: J1.A5 (CC1), R6.1
unnamed: J1.B5 (CC2), R7.1
unnamed: J3.1, R5.1
unnamed: R17.1, U1.21 (XOUT)
VBUS: C15.1, D2.1 (A1), J1.A4 (VBUS), J1.A9 (VBUS), J1.B4 (VBUS), J1.B9 (VBUS), U3.3 (VI); also elsewhere on the board

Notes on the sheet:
datasheet placement
RP2040 Clock
Power
LED
USB
Flash

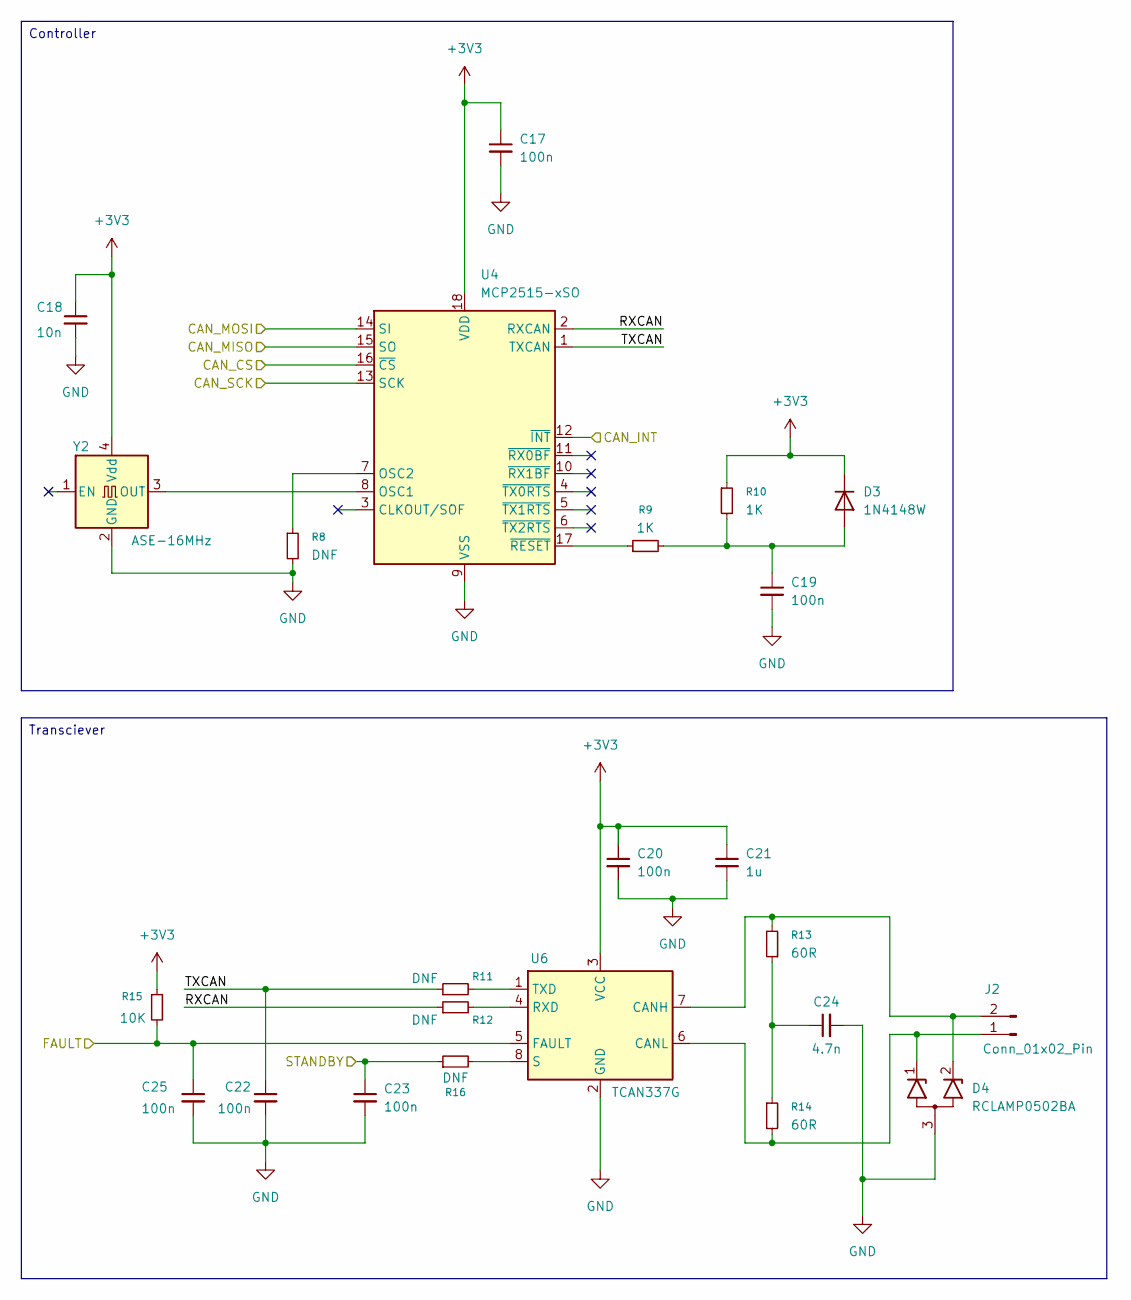
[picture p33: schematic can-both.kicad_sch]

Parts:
C17, C19, C20, C22, C23, C25: 100n; C_0603_1608Metric_Pad1.08x0.95mm_HandSolder
C18: 10n; C_0603_1608Metric_Pad1.08x0.95mm_HandSolder
C21: 1u; C_0603_1608Metric_Pad1.08x0.95mm_HandSolder
C24: 4.7n; C_0603_1608Metric_Pad1.08x0.95mm_HandSolder
D3: 1N4148W; D_SOD-123
D4: RCLAMP0502BA; SOT-416
J2: Conn_01x02_Pin; PinHeader_1x02_P2.54mm_Vertical
R8, R11, R12, R16: DNF; R_0603_1608Metric_Pad0.98x0.95mm_HandSolder
R9, R10: 1K; R_0603_1608Metric_Pad0.98x0.95mm_HandSolder
R13, R14: 60R; R_0603_1608Metric_Pad0.98x0.95mm_HandSolder
R15: 10K; R_0603_1608Metric_Pad0.98x0.95mm_HandSolder
U4: MCP2515-xSO; SOIC-18W_7.5x11.6mm_P1.27mm
U6: TCAN337G; SOIC-8_3.9x4.9mm_P1.27mm
Y2: ASE-16MHz; Oscillator_SMD_Abracon_ASE-4Pin_3.2x2.5mm

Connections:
+3V3: C17.1, C18.1, C20.1, C21.1, D3.1 (K), R10.1, R15.1, U4.18 (VDD), U6.3 (VCC), Y2.4 (Vdd); also elsewhere on the board
/CAN/RXCAN: R12.1, U4.2 (RXCAN)
/CAN/TXCAN: C22.1, R11.1, U4.1 (TXCAN)
/CAN_CS: U4.16 (~CS); also elsewhere on the board
/CAN_FAULT: C25.1, R15.2, U6.5 (FAULT); also elsewhere on the board
/CAN_INT: U4.12 (~INT); also elsewhere on the board
/CAN_SCK: U4.13 (SCK); also elsewhere on the board
/CAN_STANDBY: C23.1, R16.1; also elsewhere on the board
/N_CAN_RX: U4.15 (SO); also elsewhere on the board
/N_CAN_TX: U4.14 (SI); also elsewhere on the board
GND: C17.2, C18.2, C19.2, C20.2, C21.2, C22.2, C23.2, C24.2, C25.2, D4.3 (A), R8.2, U4.9 (VSS), U6.2 (GND), Y2.2 (GND); also elsewhere on the board
unnamed: C24.1, R13.1, R14.1
unnamed: C19.1, D3.2 (A), R9.2, R10.2
unnamed: D4.1 (K1), J2.1, R14.2, U6.6 (CANL)
unnamed: D4.2 (K2), J2.2, R13.2, U6.7 (CANH)
unnamed: U4.8 (OSC1), Y2.3 (OUT)
unnamed: R8.1, U4.7 (OSC2)
unnamed: R9.1, U4.17 (~RESET)
unnamed: R12.2, U6.4 (RXD)
unnamed: R16.2, U6.8 (S)
unnamed: R11.2, U6.1 (TXD)

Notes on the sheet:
Transciever
Controller

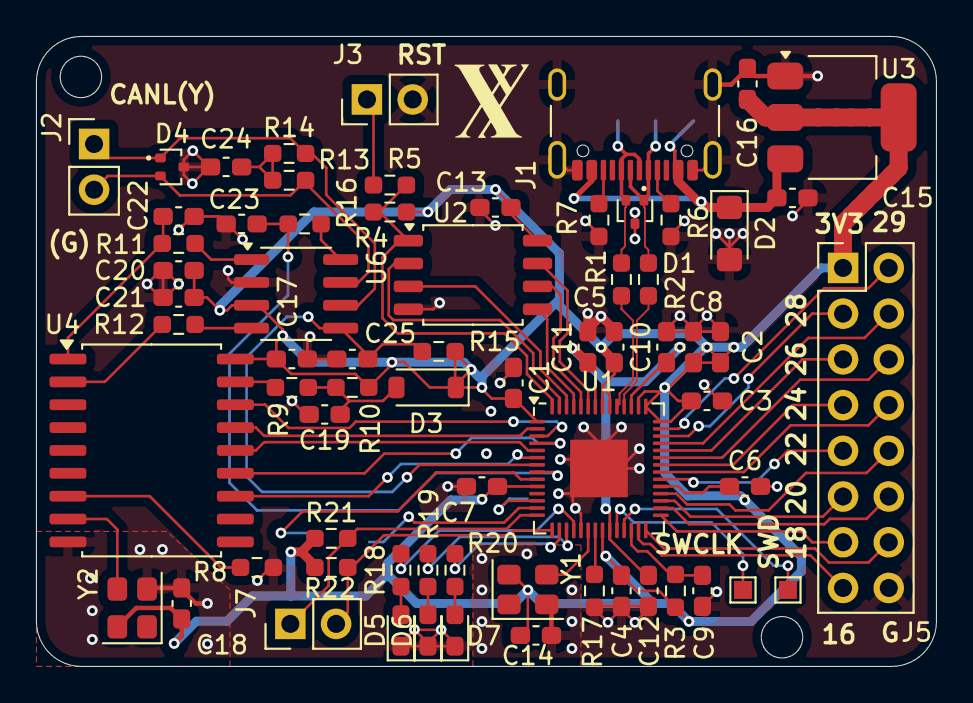
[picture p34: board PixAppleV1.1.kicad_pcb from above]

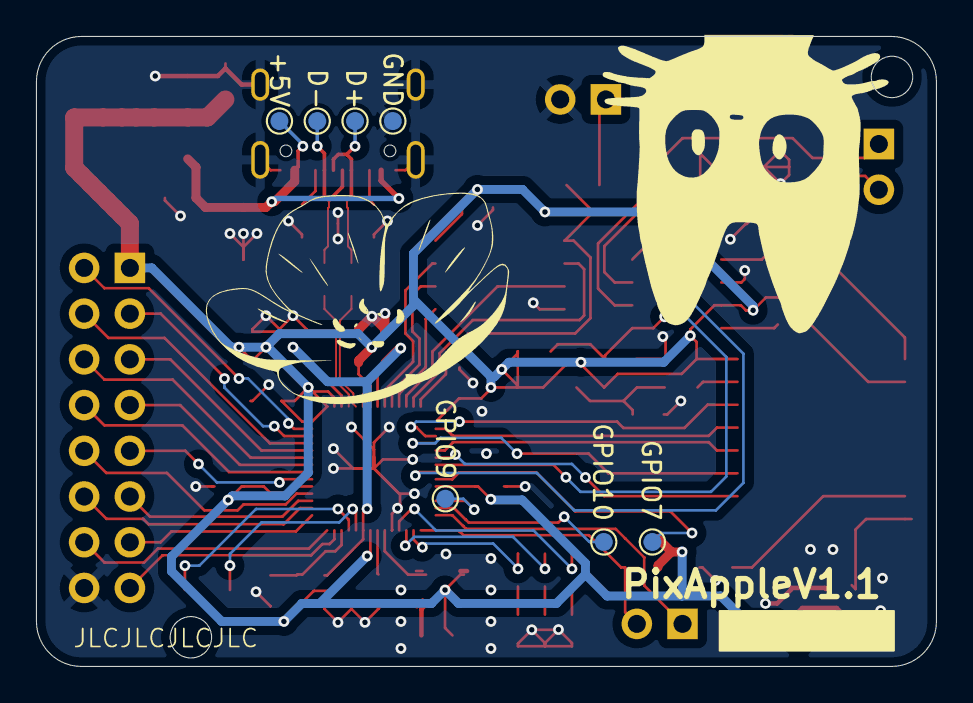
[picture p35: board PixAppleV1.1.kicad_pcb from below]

Board: 4 copper layers, 50.0 x 35.0 mm, 75 parts (7 on the bottom side), 66 nets.

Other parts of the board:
+5V: TestPoint_Pad_D1.0mm
D+: TestPoint_Pad_D1.0mm
D-: TestPoint_Pad_D1.0mm
GND: TestPoint_Pad_D1.0mm
GPIO7, GPIO9, GPIO10: TestPoint_Pad_D1.0mm
SWCLK: Pad1; TestPoint_Pad_1.0x1.0mm
SWD: Pad2; TestPoint_Pad_1.0x1.0mm

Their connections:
/GPIO7: GPIO7.1; also elsewhere on the board
/GPIO9: GPIO9.1; also elsewhere on the board
/GPIO10: GPIO10.1; also elsewhere on the board
/SWCLK: SWCLK.1; also elsewhere on the board
/SWD: SWD.1; also elsewhere on the board
/USB_D_+: D+.1; also elsewhere on the board
/USB_D_-: D-.1; also elsewhere on the board
GND: GND.1; also elsewhere on the board
VBUS: +5V.1; also elsewhere on the board

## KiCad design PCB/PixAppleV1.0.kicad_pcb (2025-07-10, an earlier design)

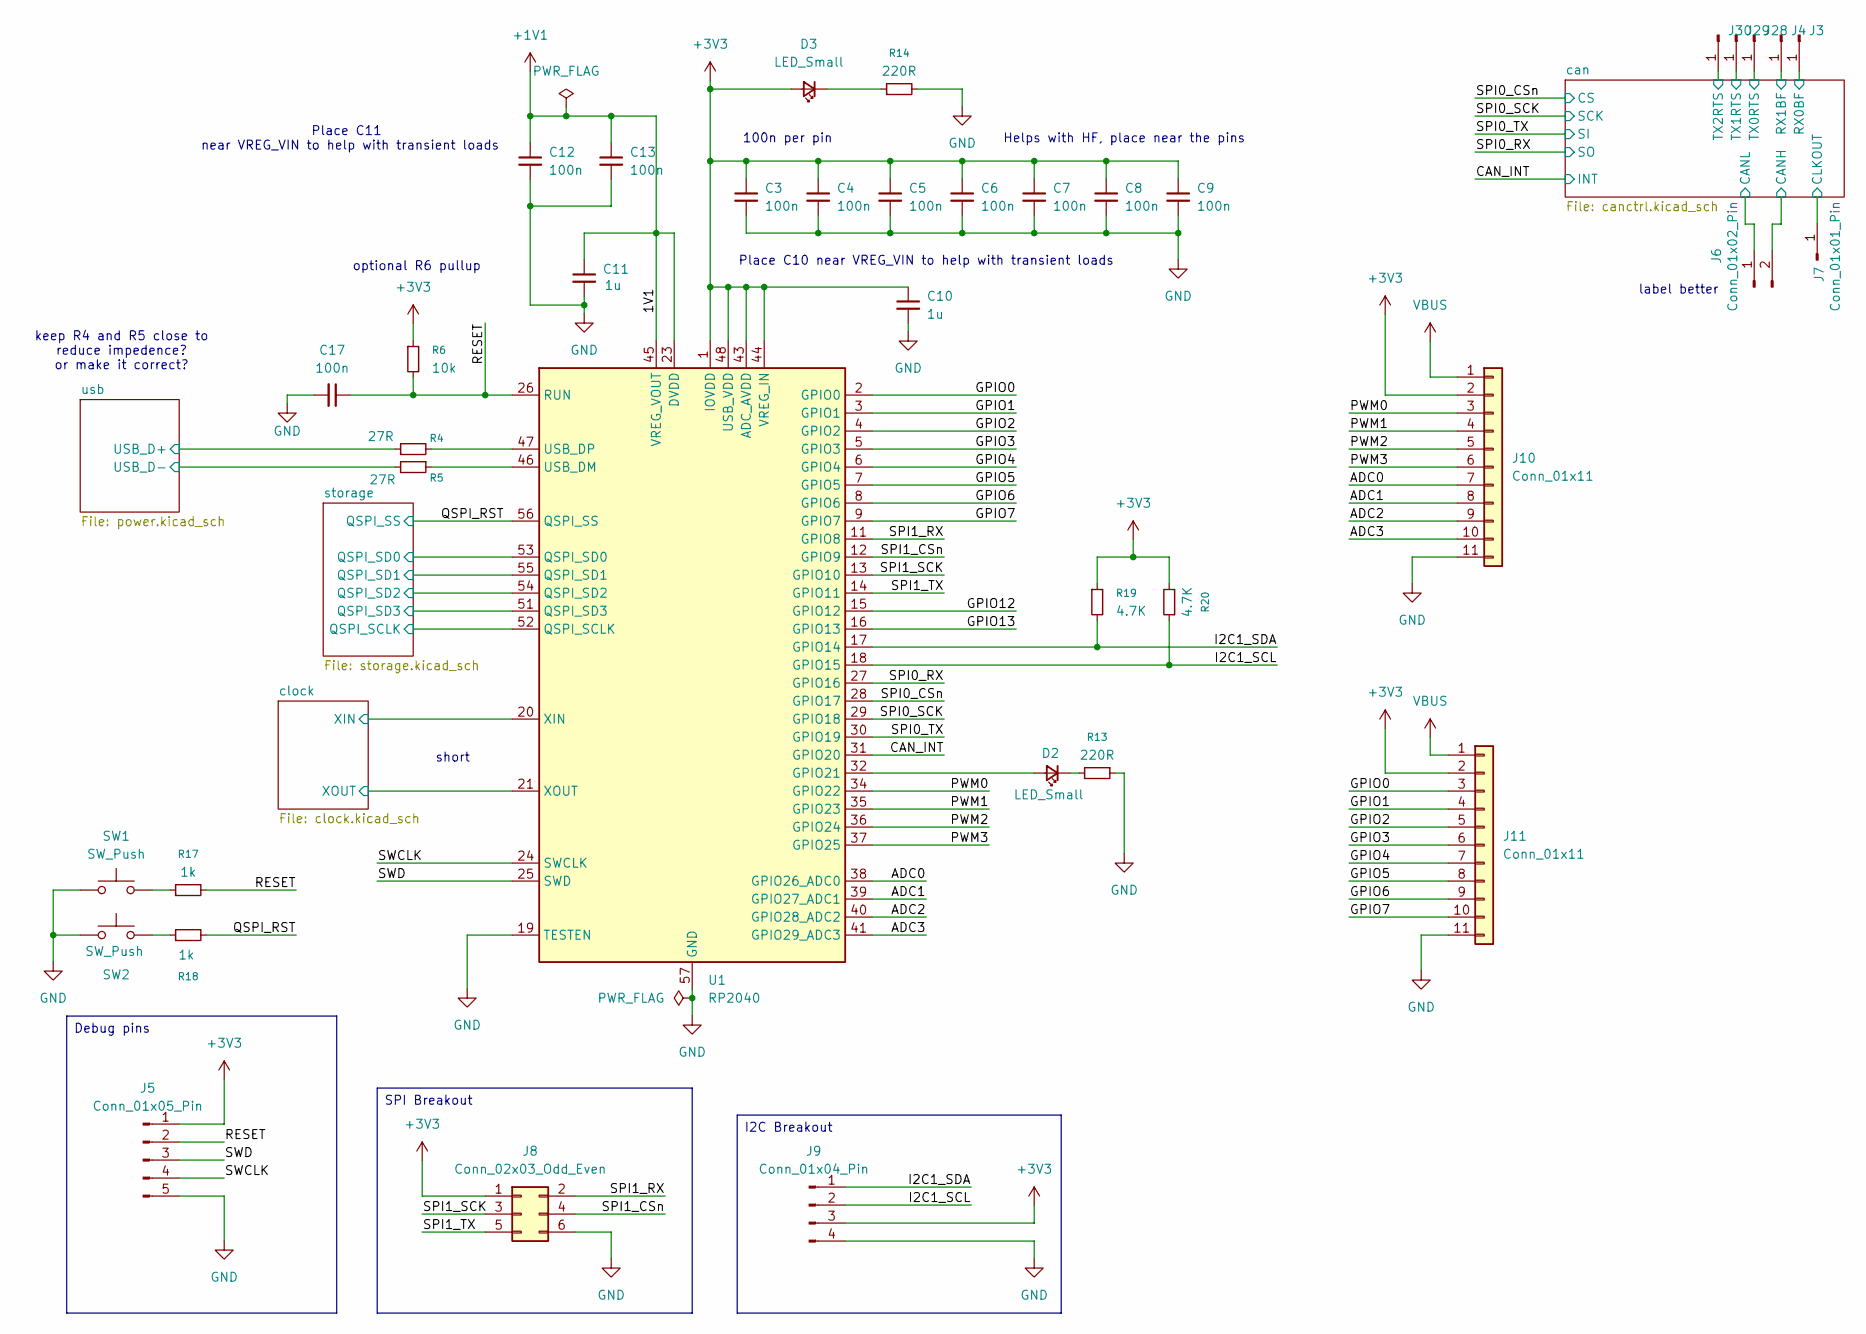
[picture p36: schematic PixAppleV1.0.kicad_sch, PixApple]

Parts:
C3, C4, C5, C6, C7, C8, C9, C12, C13, C17: 100n; C_0603_1608Metric_Pad1.08x0.95mm_HandSolder
C10, C11: 1u; C_0603_1608Metric_Pad1.08x0.95mm_HandSolder
D2, D3: LED_Small; LED_0603_1608Metric_Pad1.05x0.95mm_HandSolder
J3, J4, J7, J28, J29, J30: Conn_01x01_Pin; TestPoint_Pad_1.0x1.0mm
J5: Conn_01x05_Pin; PinHeader_1x05_P2.54mm_Vertical
J6: Conn_01x02_Pin; PinHeader_1x02_P2.54mm_Vertical
J8: Conn_02x03_Odd_Even; PinHeader_2x03_P2.54mm_Vertical
J9: Conn_01x04_Pin; PinHeader_1x04_P2.54mm_Vertical
J10, J11: Conn_01x11; PinHeader_1x11_P2.54mm_Vertical
R4, R5: 27R; R_0603_1608Metric_Pad0.98x0.95mm_HandSolder
R6: 10k; R_0603_1608Metric_Pad0.98x0.95mm_HandSolder
R13, R14: 220R; R_0603_1608Metric_Pad0.98x0.95mm_HandSolder
R17, R18: 1k; R_0603_1608Metric_Pad0.98x0.95mm_HandSolder
R19, R20: 4.7K; R_0603_1608Metric_Pad0.98x0.95mm_HandSolder
SW1, SW2: SW_Push; SW_PUSH_6mm
U1: RP2040; QFN-56-1EP_7x7mm_P0.4mm_EP3.2x3.2mm

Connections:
+1V1: C11.1, C12.1, C13.1, U1.23 (DVDD), U1.45 (VREG_VOUT), U1.50 (DVDD)
+3V3: C3.1, C4.1, C5.1, C6.1, C7.1, C8.1, C9.1, C10.1, D3.2 (A), J5.1, J8.1, J9.3, J10.2, J11.2, R6.1, R19.1, R20.2, U1.1 (IOVDD), U1.10 (IOVDD), U1.22 (IOVDD), U1.33 (IOVDD), U1.42 (IOVDD), U1.43 (ADC_AVDD), U1.44 (VREG_IN), U1.48 (USB_VDD), U1.49 (IOVDD); also elsewhere on the board
/ADC0: J10.7, U1.38 (GPIO26_ADC0)
/ADC1: J10.8, U1.39 (GPIO27_ADC1)
/ADC2: J10.9, U1.40 (GPIO28_ADC2)
/ADC3: J10.10, U1.41 (GPIO29_ADC3)
/CAN_INT: U1.31 (GPIO20); also elsewhere on the board
/GPIO0: J11.3, U1.2 (GPIO0)
/GPIO1: J11.4, U1.3 (GPIO1)
/GPIO2: J11.5, U1.4 (GPIO2)
/GPIO3: J11.6, U1.5 (GPIO3)
/GPIO4: J11.7, U1.6 (GPIO4)
/GPIO5: J11.8, U1.7 (GPIO5)
/GPIO6: J11.9, U1.8 (GPIO6)
/GPIO7: J11.10, U1.9 (GPIO7)
/GPIO12: U1.15 (GPIO12)
/GPIO13: U1.16 (GPIO13)
/I2C1_SCL: J9.2, R20.1, U1.18 (GPIO15)
/I2C1_SDA: J9.1, R19.2, U1.17 (GPIO14)
/PWM0: J10.3, U1.34 (GPIO22)
/PWM1: J10.4, U1.35 (GPIO23)
/PWM2: J10.5, U1.36 (GPIO24)
/PWM3: J10.6, U1.37 (GPIO25)
/QSPI_RST: R18.2, U1.56 (QSPI_SS); also elsewhere on the board
/RESET: C17.1, J5.2, R6.2, R17.2, U1.26 (RUN)
/SPI0_CSn: U1.28 (GPIO17); also elsewhere on the board
/SPI0_RX: U1.27 (GPIO16); also elsewhere on the board
/SPI0_SCK: U1.29 (GPIO18); also elsewhere on the board
/SPI0_TX: U1.30 (GPIO19); also elsewhere on the board
/SPI1_CSn: J8.4, U1.12 (GPIO9)
/SPI1_RX: J8.2, U1.11 (GPIO8)
/SPI1_SCK: J8.3, U1.13 (GPIO10)
/SPI1_TX: J8.5, U1.14 (GPIO11)
/SWCLK: J5.4, U1.24 (SWCLK)
/SWD: J5.3, U1.25 (SWD)
/can/CANH: J6.2; also elsewhere on the board
/can/CANL: J6.1; also elsewhere on the board
/can/CLKOUT: J7.1; also elsewhere on the board
/can/RX0BF: J3.1; also elsewhere on the board
/can/RX1BF: J4.1; also elsewhere on the board
/can/TX0RTS: J28.1; also elsewhere on the board
/can/TX1RTS: J29.1; also elsewhere on the board
/can/TX2RTS: J30.1; also elsewhere on the board
/clock/XIN: U1.20 (XIN); also elsewhere on the board
/clock/XOUT: U1.21 (XOUT); also elsewhere on the board
/storage/QSPI_SCLK: U1.52 (QSPI_SCLK); also elsewhere on the board
/storage/QSPI_SD0: U1.53 (QSPI_SD0); also elsewhere on the board
/storage/QSPI_SD1: U1.55 (QSPI_SD1); also elsewhere on the board
/storage/QSPI_SD2: U1.54 (QSPI_SD2); also elsewhere on the board
/storage/QSPI_SD3: U1.51 (QSPI_SD3); also elsewhere on the board
/usb/USB_D+: R4.1; also elsewhere on the board
/usb/USB_D-: R5.2; also elsewhere on the board
GND: C3.2, C4.2, C5.2, C6.2, C7.2, C8.2, C9.2, C10.2, C11.2, C12.2, C13.2, C17.2, J5.5, J8.6, J9.4, J10.11, J11.11, R13.1, R14.2, SW1.1, SW2.1, U1.19 (TESTEN), U1.57 (GND); also elsewhere on the board
unnamed: D2.2 (A), U1.32 (GPIO21)
unnamed: D2.1 (K), R13.2
unnamed: D3.1 (K), R14.1
unnamed: R17.1, SW1.2
unnamed: R18.1, SW2.2
unnamed: R5.1, U1.46 (USB_DM)
unnamed: R4.2, U1.47 (USB_DP)
VBUS: J10.1, J11.1; also elsewhere on the board

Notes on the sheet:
optional R6 pullup
keep R4 and R5 close to reduce impedence? or make it correct?
100n per pin
label better
Place C10 near VREG_VIN to help with transient loads
Helps with HF, place near the pins
short
Place C11 near VREG_VIN to help with transient loads
Debug pins
I2C Breakout
SPI Breakout

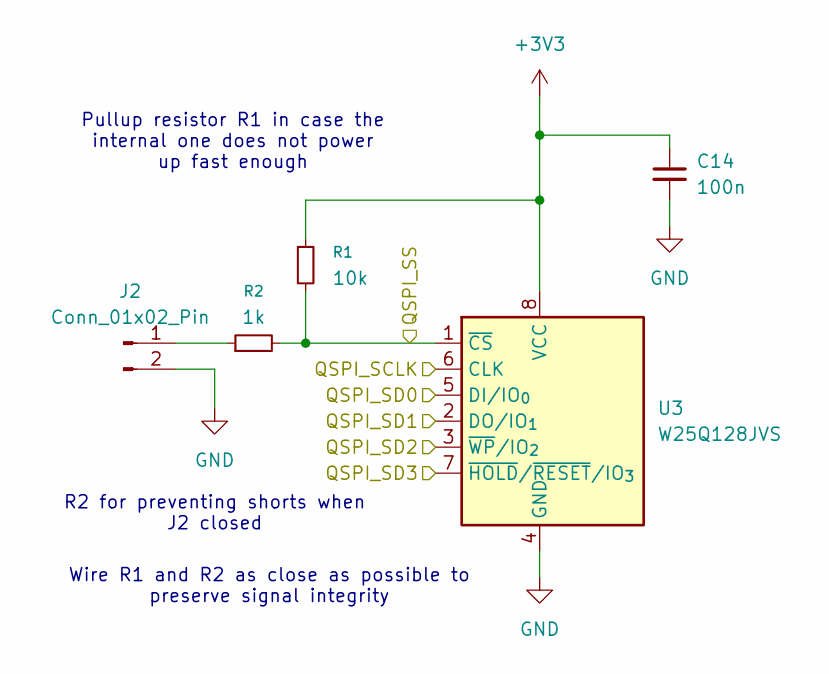
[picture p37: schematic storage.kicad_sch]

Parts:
C14: 100n; C_0603_1608Metric_Pad1.08x0.95mm_HandSolder
J2: Conn_01x02_Pin; PinHeader_1x02_P2.54mm_Vertical
R1: 10k; R_0603_1608Metric_Pad0.98x0.95mm_HandSolder
R2: 1k; R_0603_1608Metric_Pad0.98x0.95mm_HandSolder
U3: W25Q128JVS; SOIC-8_5.3x5.3mm_P1.27mm

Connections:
+3V3: C14.1, R1.1, U3.8 (VCC); also elsewhere on the board
/QSPI_RST: R1.2, R2.2, U3.1 (~CS); also elsewhere on the board
/storage/QSPI_SCLK: U3.6 (CLK); also elsewhere on the board
/storage/QSPI_SD0: U3.5 (DI/IO_{0}); also elsewhere on the board
/storage/QSPI_SD1: U3.2 (DO/IO_{1}); also elsewhere on the board
/storage/QSPI_SD2: U3.3 (~WP/IO_{2}); also elsewhere on the board
/storage/QSPI_SD3: U3.7 (~HOLD/~RESET/IO_{3}); also elsewhere on the board
GND: C14.2, J2.2, U3.4 (GND); also elsewhere on the board
unnamed: J2.1, R2.1

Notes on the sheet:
Wire R1 and R2 as close as possible to preserve signal integrity
Pullup resistor R1 in case the internal one does not power up fast enough
R2 for preventing shorts when J2 closed

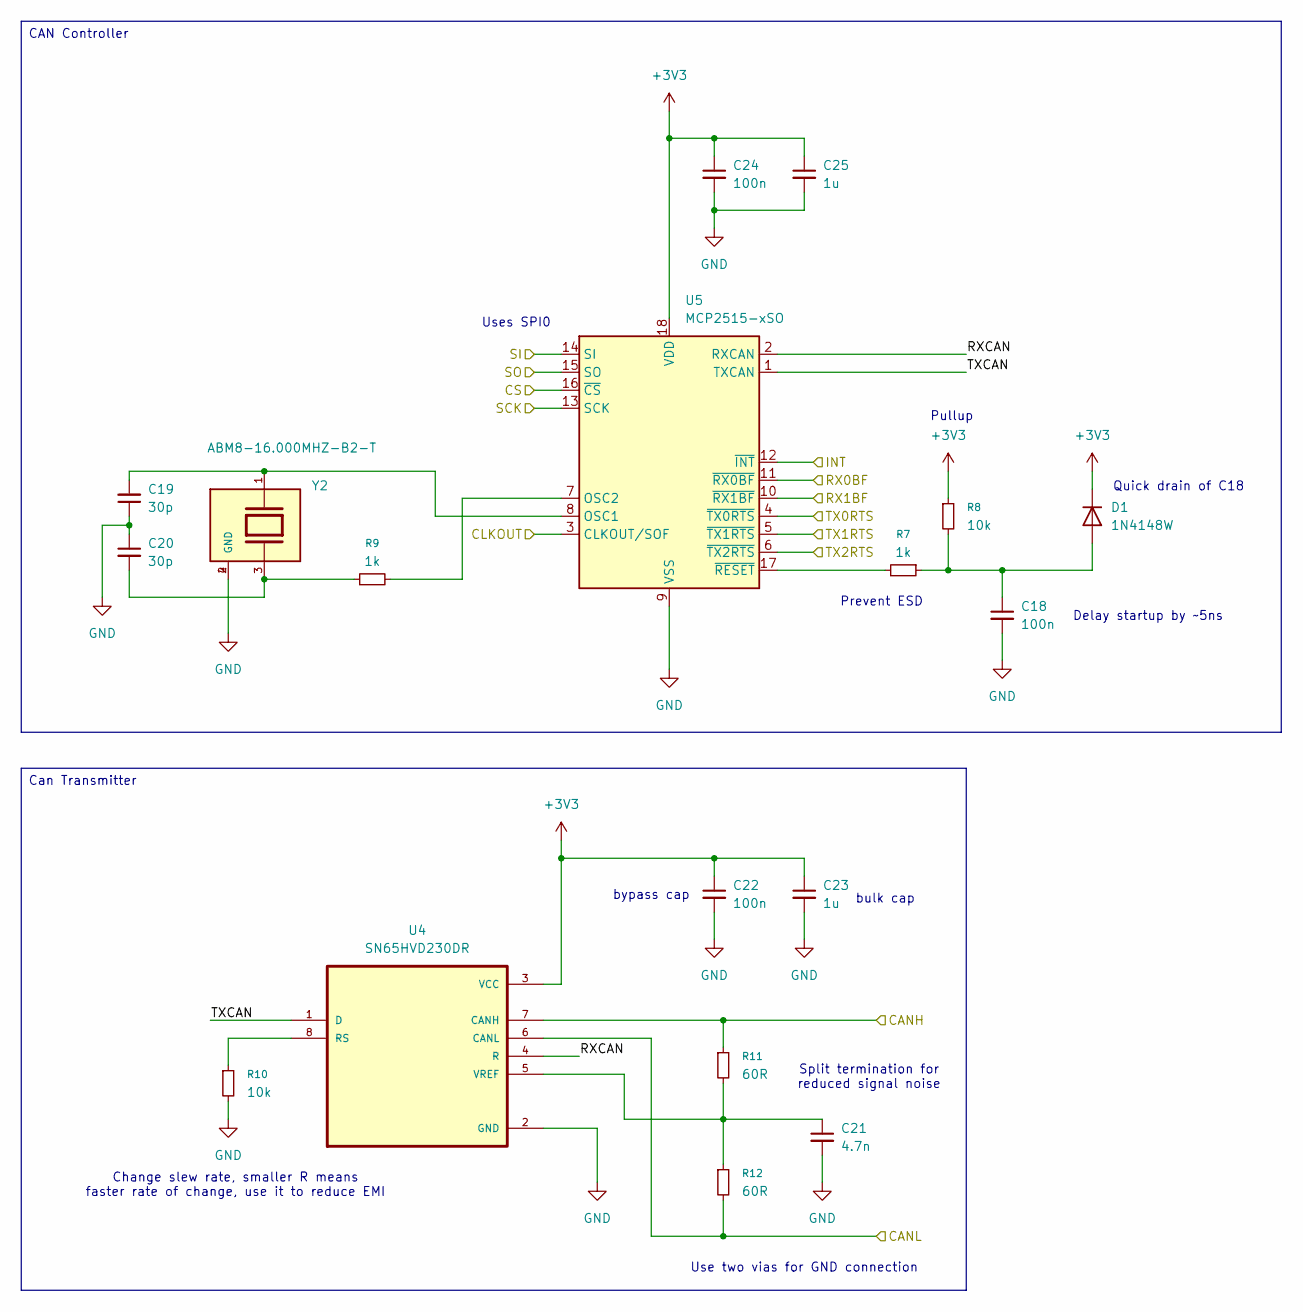
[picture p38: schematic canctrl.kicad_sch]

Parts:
C18, C22, C24: 100n; C_0603_1608Metric_Pad1.08x0.95mm_HandSolder
C19, C20: 30p; C_0603_1608Metric_Pad1.08x0.95mm_HandSolder
C21: 4.7n; C_0603_1608Metric_Pad1.08x0.95mm_HandSolder
C23, C25: 1u; C_0603_1608Metric_Pad1.08x0.95mm_HandSolder
D1: 1N4148W; D_SOD-123
R7, R9: 1k; R_0603_1608Metric_Pad0.98x0.95mm_HandSolder
R8, R10: 10k; R_0603_1608Metric_Pad0.98x0.95mm_HandSolder
R11, R12: 60R; R_0603_1608Metric_Pad0.98x0.95mm_HandSolder
U4: SN65HVD230DR; SOIC127P599X175-8N
U5: MCP2515-xSO; SOIC-18W_7.5x11.6mm_P1.27mm
Y2: ABM8-16.000MHZ-B2-T; XTAL_ABM8-16.000MHZ-B2-T; PARTREV 44041

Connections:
+3V3: C22.1, C23.1, C24.1, C25.1, D1.1 (K), R8.1, U4.3 (VCC), U5.18 (VDD); also elsewhere on the board
/CAN_INT: U5.12 (~INT); also elsewhere on the board
/SPI0_CSn: U5.16 (~CS); also elsewhere on the board
/SPI0_RX: U5.15 (SO); also elsewhere on the board
/SPI0_SCK: U5.13 (SCK); also elsewhere on the board
/SPI0_TX: U5.14 (SI); also elsewhere on the board
/can/CANH: R11.1, U4.7 (CANH); also elsewhere on the board
/can/CANL: R12.2, U4.6 (CANL); also elsewhere on the board
/can/CLKOUT: U5.3 (CLKOUT/SOF); also elsewhere on the board
/can/RX0BF: U5.11 (~RX0BF); also elsewhere on the board
/can/RX1BF: U5.10 (~RX1BF); also elsewhere on the board
/can/RXCAN: U4.4 (R), U5.2 (RXCAN)
/can/TX0RTS: U5.4 (~TX0RTS); also elsewhere on the board
/can/TX1RTS: U5.5 (~TX1RTS); also elsewhere on the board
/can/TX2RTS: U5.6 (~TX2RTS); also elsewhere on the board
/can/TXCAN: U4.1 (D), U5.1 (TXCAN)
GND: C18.2, C19.1, C20.1, C21.2, C22.2, C23.2, C24.2, C25.2, R10.2, U4.2 (GND), U5.9 (VSS), Y2.2 (GND), Y2.4 (GND); also elsewhere on the board
unnamed: C20.2, R9.1, Y2.3
unnamed: C18.1, D1.2 (A), R7.1, R8.2
unnamed: R10.1, U4.8 (RS)
unnamed: C21.1, R11.2, R12.1, U4.5 (VREF)
unnamed: C19.2, U5.8 (OSC1), Y2.1
unnamed: R9.2, U5.7 (OSC2)
unnamed: R7.2, U5.17 (~RESET)

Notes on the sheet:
Uses SPI0
Delay startup by ~5ns
bypass cap
Pullup
Use two vias for GND connection
Change slew rate, smaller R means faster rate of change, use it to reduce EMI
Split termination for reduced signal noise
Prevent ESD
Quick drain of C18
bulk cap
Can Transmitter
CAN Controller

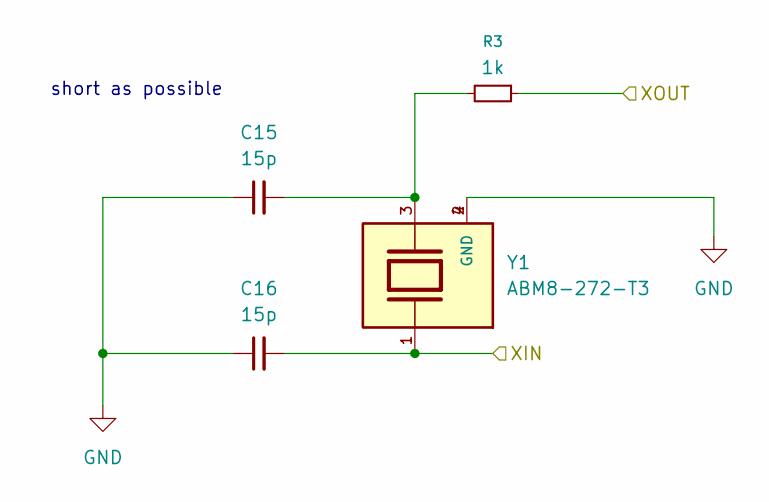
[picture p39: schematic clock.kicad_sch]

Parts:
C15, C16: 15p; C_0603_1608Metric_Pad1.08x0.95mm_HandSolder
R3: 1k; R_0603_1608Metric_Pad0.98x0.95mm_HandSolder
Y1: ABM8-272-T3; XTAL_ABM8-272-T3; PARTREV 07-29-20

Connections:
/clock/XIN: C16.2, Y1.1; also elsewhere on the board
/clock/XOUT: R3.1; also elsewhere on the board
GND: C15.1, C16.1, Y1.2 (GND), Y1.4 (GND); also elsewhere on the board
unnamed: C15.2, R3.2, Y1.3

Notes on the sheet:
short as possible

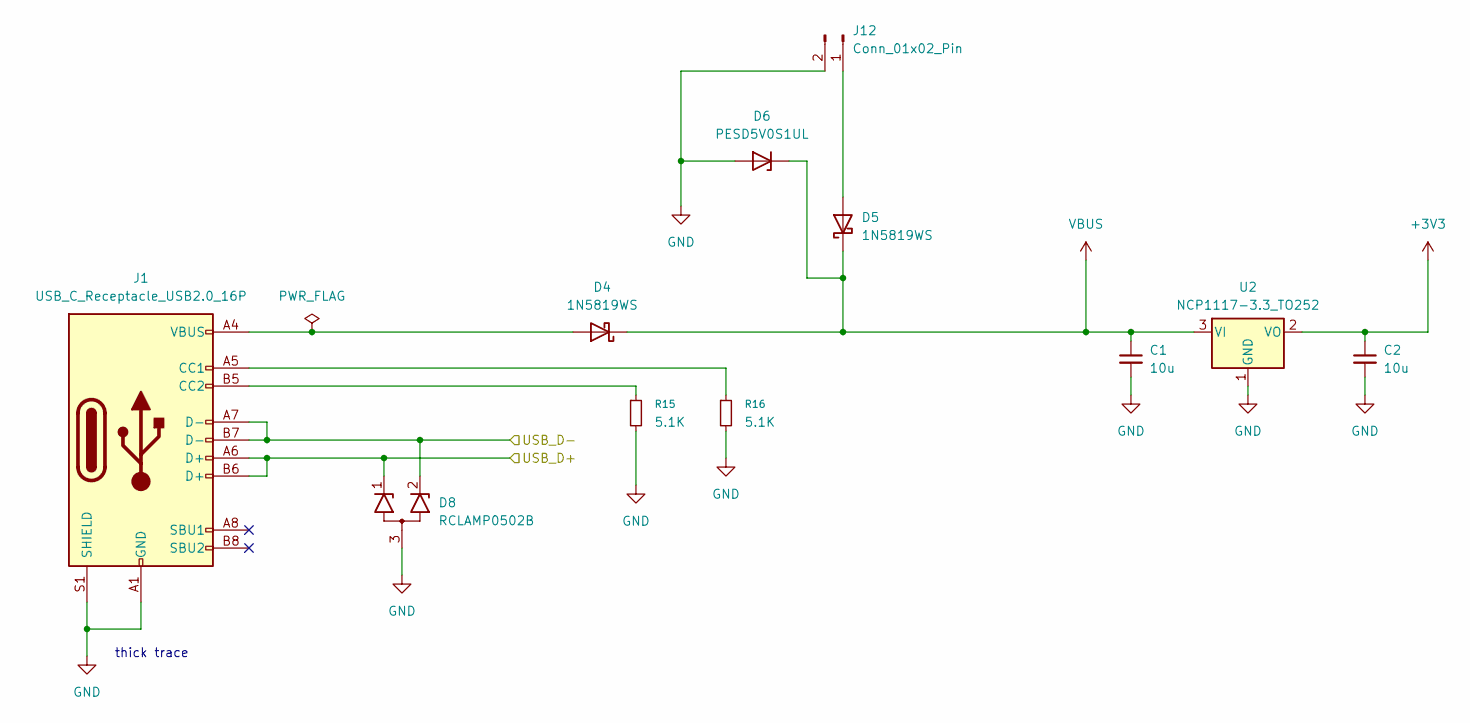
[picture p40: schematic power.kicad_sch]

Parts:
C1, C2: 10u; C_0603_1608Metric_Pad1.08x0.95mm_HandSolder
D4, D5: 1N5819WS; D_SOD-323
D6: PESD5V0S1UL; D_SOD-882
D8: RCLAMP0502B; SOT-416
J1: USB_C_Receptacle_USB2.0_16P; USB_C_Receptacle_GCT_USB4105-xx-A_16P_TopMnt_Horizontal
J12: Conn_01x02_Pin; PinHeader_1x02_P2.54mm_Vertical
R15, R16: 5.1K; R_0603_1608Metric_Pad0.98x0.95mm_HandSolder
U2: NCP1117-3.3_TO252; TO-252-2

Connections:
+3V3: C2.1, U2.2 (VO); also elsewhere on the board
/usb/USB_D+: D8.1 (K1), J1.A6 (D+), J1.B6 (D+); also elsewhere on the board
/usb/USB_D-: D8.2 (K2), J1.A7 (D-), J1.B7 (D-); also elsewhere on the board
GND: C1.2, C2.2, D6.2 (A), D8.3 (A), J1.A1 (GND), J1.A12 (GND), J1.B1 (GND), J1.B12 (GND), J1.S1 (SHIELD), J12.2, R15.2, R16.2, U2.1 (GND); also elsewhere on the board
unnamed: D4.2 (A), J1.A4 (VBUS), J1.A9 (VBUS), J1.B4 (VBUS), J1.B9 (VBUS)
unnamed: D5.2 (A), J12.1
unnamed: J1.A5 (CC1), R16.1
unnamed: J1.B5 (CC2), R15.1
VBUS: C1.1, D4.1 (K), D5.1 (K), D6.1 (K), U2.3 (VI); also elsewhere on the board

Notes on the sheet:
thick trace

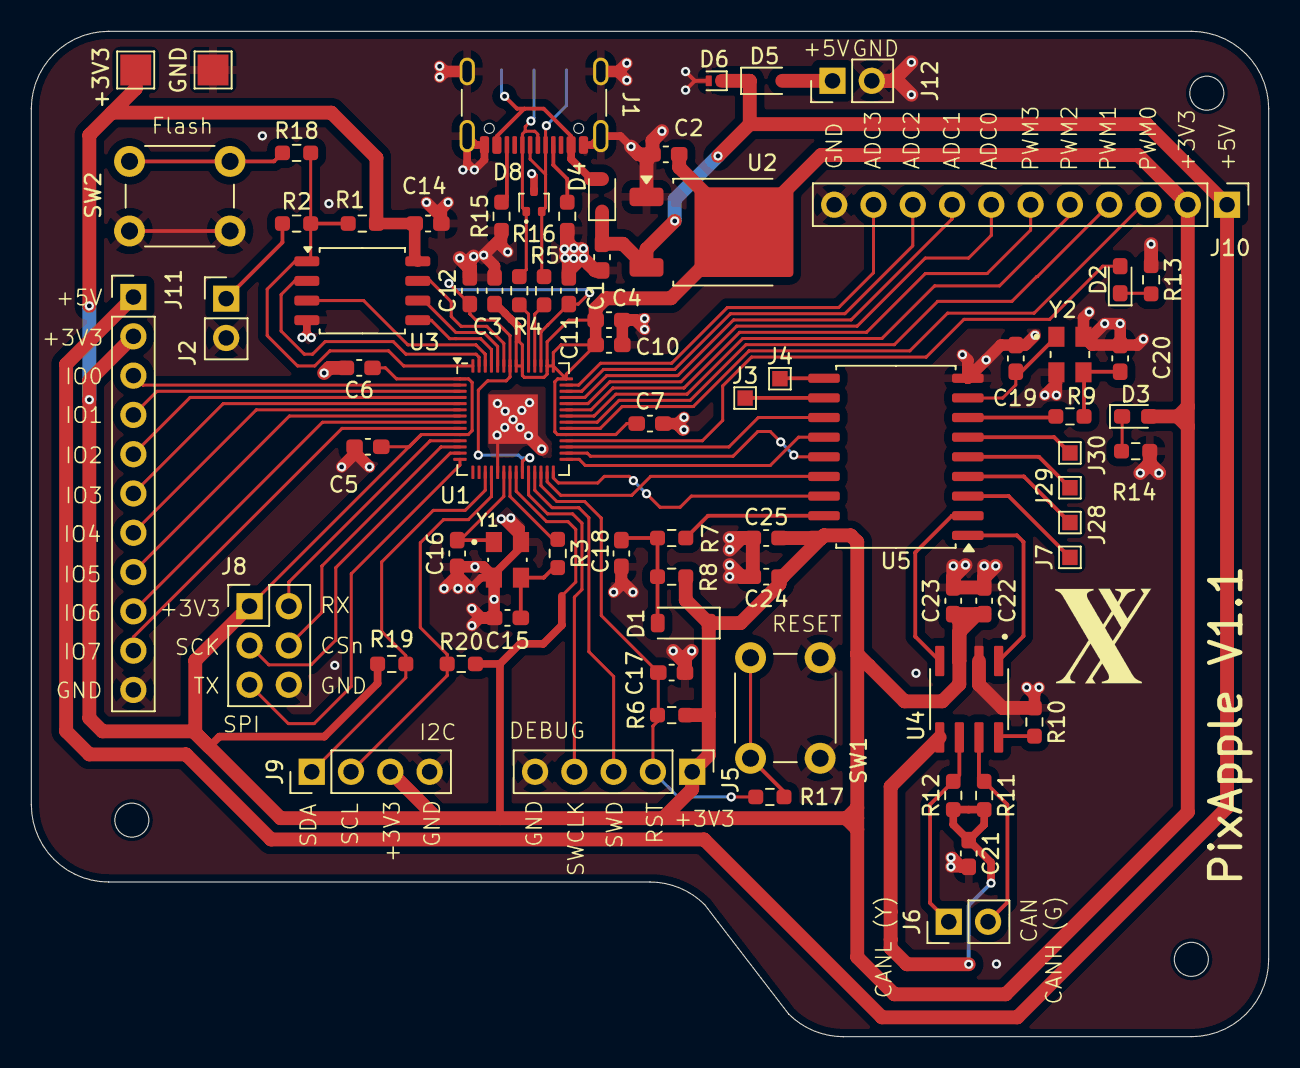
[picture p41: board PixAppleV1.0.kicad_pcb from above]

Board: 2 copper layers, 80.0 x 65.0 mm, 75 parts (0 on the bottom side), 74 nets.

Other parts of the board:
+3V3: TestPoint_Pad_2.0x2.0mm
GND: TestPoint_Pad_2.0x2.0mm

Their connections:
+3V3: +3V3.1; also elsewhere on the board
GND: GND.1; also elsewhere on the board

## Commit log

2025-07-06 MCP2515 design, kicad sucks
    [PixApple.kicad_pcb, PixApple.kicad_sch, can.kicad_sch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]
2025-07-07 CAN bus done?
    [PixApple.kicad_pcb, PixApple.kicad_sch, canctrl.kicad_sch]
2025-07-08 Routing PCB
    [PixApple.kicad_pcb, PixApple.kicad_sch, canctrl.kicad_sch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]
2025-07-09 Redo time, pcb too close
    [PixApple.kicad_pcb]
2025-07-09 PCB routing, better placement
    [PixApple.kicad_pcb, PixApple.kicad_sch, canctrl.kicad_sch]
2025-07-09 Finished PCB routing
    [PixApple.kicad_pcb, PixApple.kicad_sch, power.kicad_sch]
2025-07-09 labeling done
    [PixApple.kicad_pcb]
2025-07-10 Writeup + case
    [PixApple.kicad_pcb, PixApple.kicad_sch, assembly.FCStd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]
2025-07-10 Parst csv
    [parts.csv]
2025-07-10 BOM update
2025-07-10 parts update
    [parts.csv]
2025-07-10 Updated values
    [parts.csv]
2025-07-10 Fix pullup, connected 3V3 completely
    [PixApple.kicad_pcb, PixApple.kicad_sch, parts.csv]
2025-07-10 esd, pullup, error fix
    [PixApple.kicad_pcb, PixApple.kicad_sch, power.kicad_sch]
2025-07-12 Completely new setup omg
    [PixAppleV1.0.kicad_pcb, PixAppleV1.0.kicad_sch, PixAppleV1.1.kicad_pcb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]
2025-07-13 BOM will finish soon
    [PixAppleV1.1.kicad_pcb, bom.csv, positions.csv]
2025-07-13 New bom
2025-07-13 BOM done
    [bom.csv, parts.csv]
2025-07-13 added step files
    [case-bottom.step, case-top.step, case.FCStd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]
2025-07-13 BOM changes
    [bom.csv]
2025-07-13 add pcb to prod
    [bom.csv, positions.csv]
